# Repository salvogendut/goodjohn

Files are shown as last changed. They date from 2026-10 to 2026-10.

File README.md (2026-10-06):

# Goodjohn

Goodjohn is a Raspberry Pi Pico interface for using an Amstrad CPC keyboard as
a USB keyboard on a PC. This repository holds the firmware, wiring guides and
a prototype Pico carrier PCB.

> [!WARNING]
> **USB keyboard use only.** Physically disconnect the keyboard from the CPC
> motherboard before connecting it to the Pico, even if the CPC is powered off.
> **The keyboard cannot operate the CPC and the PC at the same time.** This
> interface does not provide simultaneous use or a pass-through connection to
> the CPC. Switching the CPC off is not a substitute for disconnecting it.

The first prototype uses an **original RP2040 Pico**, an **English CPC/QWERTY
keyboard**, and **exclusive control of a keyboard disconnected from the CPC
motherboard**. These are the agreed initial requirements. The passive keyboard
connects to Pico GPIO; the Pico's USB connector connects to the PC.

Minimal wiring from a Raspberry Pi Pico to a 19-pin CPC keyboard connector

The drawing's **J1 adapter connector** uses the contact numbering of Bread80's
CPC464 **J3 keyboard connector**. Its square contact 1 is shown at the bottom;
labels give **GPIO / physical Pico pin**. See the [pinout sheet](docs/pinout.pdf)
for connector checks and assembly details.

**Original CPC464 PCB-style keyboard:** use the inline wiring above. Its
19-signal connector pinout is shared by rgbwalker's keyboard and Bread80's
CPC464 SMT **J3** connector. Some versions use a 20-position footprint with one
unused contact. Later CPC464 membrane keyboards use the two-ribbon connection
described below; connector orientation must still be checked on the actual board.

## Current state

There is a buildable C firmware foundation using the Raspberry Pi Pico SDK and
TinyUSB, plus native tests. It scans the physical 10-by-9 CPC464 wiring, debounces
each contact for 5 ms, and sends standard USB HID boot-keyboard reports. The
default scan period is 1 ms. Reports support six regular keys plus modifiers;
more regular keys produce HID ErrorRollOver until the count falls back to six.

Boards without diodes use conservative ghost suppression: new presses in an
ambiguous rectangle are blocked, while already accepted keys and unrelated keys
continue to work. This cannot recover arbitrary chords or detect a release that
is electrically hidden by other held keys. Fully diode-isolated boards can turn
the filter off at build time.

**Status: host tests pass; basic typing works on rgbwalker V1.2.** On 2026-10-06,
the user confirmed the complete number row (`1234567890`), all three letter rows,
Esc and main Enter with the completed 19-wire direct harness. Replacing the
earlier ribbon/jumper path resolved the incorrect characters using the existing
firmware and pin map. The exact fault in that earlier assembly is still unknown.
See the [staged wiring checks and test record](docs/wiring.md#staged-bring-up-for-rgbwalker-v12).

The remaining individual keys, modifiers, chords, cable timing, and USB
suspend/resume and current still need recorded bench tests. The carrier PCB
below is designed and checked, but has not been manufactured or bench-tested.

## Pico carrier PCB prototype

The [v1 carrier](hardware/pico-carrier-v1/README.md) is an **80 × 66 mm, two-layer
board** with a socketed RP2040 Pico, the inline 19-pin connector and separate
10-pin ribbon A/B headers. Use one keyboard through **J1 OR J2 + J3**. It keeps
the tested firmware pin map and powers the Pico through its existing USB port.

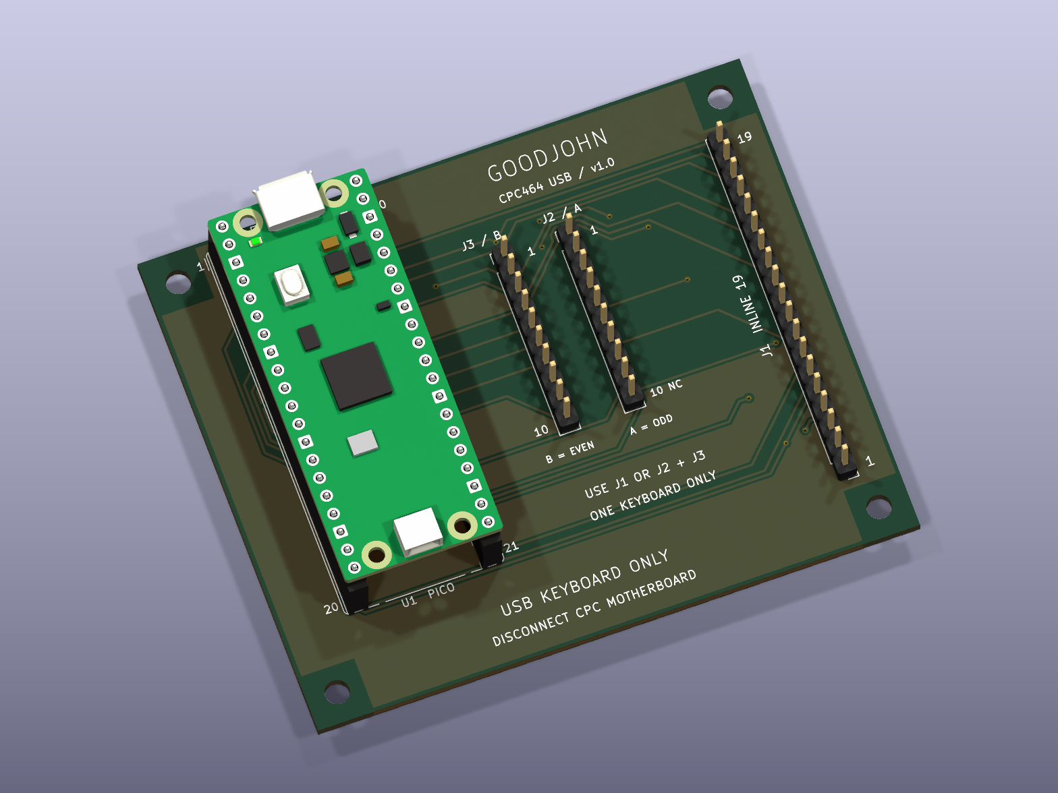
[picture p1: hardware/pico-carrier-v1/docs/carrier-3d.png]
KiCad render of the Goodjohn Pico carrier prototype


The [KiCad project](hardware/pico-carrier-v1/goodjohn-carrier.kicad_pro),
[schematic PDF](hardware/pico-carrier-v1/docs/schematic.pdf),
[assembly guide](hardware/pico-carrier-v1/docs/assembly.pdf),
[BOM](hardware/pico-carrier-v1/bom.csv) and
[Gerber/drill ZIP](hardware/pico-carrier-v1/fabrication/goodjohn-carrier-v1-gerbers.zip)
are included. ERC, DRC and schematic/PCB parity checks pass; an independent
pin-map check matches all 19 signals to the firmware and existing wiring SVGs.
**This is an unbuilt prototype, and the CPC motherboard must remain physically
disconnected.** The carrier headers accept 2.54 mm mating harnesses; bare
membrane tails need an appropriate connector adapter.

## Keyboard projects

| Project | Initial integration |
| --- | --- |
| [rgbwalker's CPC464 Cherry keyboard](https://github.com/rgbwalker/Amstrad_CPC_464_new_Cherry_Keyboard) | V1.2: digits, all letter rows, Esc and main Enter confirmed with a direct 19-wire harness. Further key/chord tests pending; retain ghost suppression. |
| [Bread80 CPC464 SMT mechanical keyboard](https://github.com/Bread80/CPC_Keyboards/tree/main/Keyswitch_CPC464_SMT) | J3 inline and J1 two-ribbon schemes traced from the KiCad PCB. J1 uses CPC464 link settings; hardware validation pending. Verified per-key diodes allow disabling ghost suppression. |
| [Bread80 tactile keyboard](https://github.com/Bread80/CPC_Keyboards/tree/main/Tactile) | Same CPC key arrangement, no diodes; connector adapter still needs checking. |
| [Bread80 CPC6128 SMT keyboard](https://github.com/Bread80/CPC_Keyboards/tree/main/Keyswitch_CPC6128_SMT) | Upstream describes this as a design-stage board; not a validated adapter target. |

Start with [the wiring notes](docs/wiring.md). Connector families are not
interchangeable just because the logical CPC matrix is the same.

For the workbench, use the [ASCII pinout sheet](docs/pinout.txt) or the
[four-page printable PDF](docs/pinout.pdf). These include the Bread80 J3 wire
list, a full Pico header diagram, assembly steps and continuity checks, plus
V1.2 connector orientation and a direct two-wire test for rgbwalker. Regenerate
both with `python3 scripts/generate_pinout.py` after installing
`scripts/requirements-docs.txt` in a Python virtual environment.
Regenerate the README's [SVG wiring diagram](docs/wiring.svg) with
`python3 scripts/generate_wiring_svg.py` in the same environment. It reuses the
Pico artwork from the supplied [pico-pinout.svg](pico-pinout.svg) and the same
firmware-derived wiring data as the sheets.

### Alternate connection: two 10-pin ribbons

Bread80's **CPC464 SMT keyboard J1**, configured for CPC464, can use two 10-way
ribbons with the existing Pico GPIO assignments. Bridge **LK1 pads 1-2** and
**LK2 pads 1-2**; leave **LK3 and the bonus links open**. This alternate harness
is source-checked and has not yet been bench-tested.

Bread80 J1 two-ribbon wiring to Raspberry Pi Pico

The diagram distinguishes ribbon positions from J1 PCB pad numbers. **J1 pad 19
is unused; pad 20 is connected.** Here J1 refers to Bread80's keyboard connector.
Use the [complete wiring scheme and orientation guide](docs/wiring-dual-ribbon.md),
[ASCII pinout](docs/pinout-dual-ribbon.txt), or [two-page PDF](docs/pinout-dual-ribbon.pdf).
This mapping is specific to the CPC464 setting; CPC6128 and Tactile connectors
need separate mappings. Regenerate these files with
`python3 scripts/generate_dual_ribbon.py` in the same documentation environment.

### Original CPC464 keyboard PCB

The original CPC464 keyboard PCB with the inline 19-wire connection is also
expected to work: its passive switch matrix matches the arrangement targeted
by this firmware, as shown in the
[Amstrad service manual](https://retronik.silicium.org/DOCUMENTS/Info/Amstrad_CPC/Amstrad%20CPC464%20CTM640%20GT64%20Service%20Manual.pdf).
The existing keymap should apply to the English/QWERTY version.

Disconnect the keyboard from the CPC motherboard, even when the CPC is powered
off; the Pico takes over keyboard scanning. Verify your connector's numbering,
orientation and switch continuity against the wiring notes before connecting it.
Keep `GOODJOHN_MATRIX_HAS_DIODES=OFF` (the default), since the original matrix
lacks per-key diodes and needs ghost suppression. Compatibility is expected but
has not yet been tested on original hardware; other connector revisions may
require a different harness.

## Build

Prerequisites: CMake, Make or Ninja, Python 3, an Arm bare-metal GCC toolchain
(`arm-none-eabi-gcc` and `arm-none-eabi-g++`), and the Pico SDK. A native C++
compiler is also needed if the SDK builds picotool instead of using an installed
copy. The development build was checked with SDK **2.2.0**, its pinned TinyUSB
submodule, Arm GNU **14.2.Rel1**, and picotool **2.3.1**.

For an SDK checkout outside this repository:

```sh
git clone --branch 2.2.0 --depth 1 https://github.com/raspberrypi/pico-sdk.git ../pico-sdk
git -C ../pico-sdk submodule update --init --depth 1 lib/tinyusb
cmake -S . -B build -DPICO_SDK_PATH="$(pwd)/../pico-sdk" -DPICO_BOARD=pico -DCMAKE_BUILD_TYPE=Release
cmake --build build --parallel
```

Put the compiler's `bin` directory on `PATH`, or set
`-DPICO_TOOLCHAIN_PATH=/path/to/arm-toolchain`. CMake uses an installed picotool
when available (`-Dpicotool_DIR=/path/to/picotool/cmake-directory`); otherwise the
SDK downloads and builds it, which needs network access.

The output is `build/goodjohn.uf2`. Hold BOOTSEL while connecting the Pico over
USB, then copy the UF2 to its `RPI-RP2` volume. This replaces the existing Pico
application. No hardware has been flashed as part of the initial setup.

For a board with verified diodes on every connected switch:

```sh
cmake -S . -B build -DGOODJOHN_MATRIX_HAS_DIODES=ON
cmake --build build --parallel
```

Leave this option OFF for original membranes, the rgbwalker Cherry board, and
the Bread80 tactile board. Edit `src/board_config.h` to change the GPIO wiring.

The default USB VID/PID (`CAFE:4011`) are development placeholders, not an
assignment to this project. A distributed product needs an authorized pair,
set using `GOODJOHN_USB_VID` and `GOODJOHN_USB_PID` CMake variables.

## Initial key behavior

The keymap sends PC key usages, not CPC character codes. Select the desired PC
keyboard layout in the host OS. Letters and digits follow English QWERTY, but
shifted symbols are not guaranteed to match the CPC legends.

| CPC key | PC behavior |
| --- | --- |
| DEL / CLR | Backspace / forward Delete |
| Main Enter / keypad Enter | Enter / keypad Enter |
| COPY | Left Alt |
| Either Shift | Left Shift (both switches share one matrix contact) |
| CTRL / CAPS LOCK | Left Control / Caps Lock |
| Numeric keypad | PC keypad usages; Num Lock state is controlled by the host |
| `^ £` / `- =` / `@ \|` | PC Equal / Minus / Grave key positions |
| `; +` / `: *` | PC Semicolon / Apostrophe key positions |
| Bread80 bonus switches | Unmapped initially |

There is no Fn layer yet, so F1–F12, GUI and Num Lock have no default bindings.
For early testing, set Num Lock using the PC's existing or on-screen keyboard.
The map lives in `src/keymap.c`; exact CPC symbol translation and additional
layouts are separate follow-up work. Host lock LED reports are accepted, but no
physical lock LEDs or USB remote wakeup are implemented.

## Test without a Pico SDK

```sh
cmake -S . -B build-host -DGOODJOHN_HOST_TESTS=ON
cmake --build build-host
ctest --test-dir build-host --output-on-failure
```

These tests cover contact bounce, independent debounce clocks, timer wrap,
ambiguous chords and recovery, the separate DEL column, modifier reports,
keypad Enter, and six-key overflow/recovery. They do not simulate USB hardware.

## Next hardware milestone

1. Pick the exact keyboard PCB revision and verify the connector with a meter.
2. Wire a Pico prototype and check single keys, modifiers, DEL, both Enter keys,
   press/release bounce and multi-key chords on a PC.
3. Measure scan settling with the intended cable, check suspend/resume and
   reconnect behavior, and settle the missing PC-key bindings.
4. Capture the proven wiring in an interface schematic and PCB with appropriate
   connector orientation, protection and optional lock LEDs.

## References

The adjacent keyboard projects are reference inputs and retain their respective
licenses; no upstream PCB or image assets are copied into this repository.
Exact local revisions and electrical findings are recorded in
[the wiring notes](docs/wiring.md).

Firmware references: [Pico SDK 2.2.0](https://github.com/raspberrypi/pico-sdk/tree/2.2.0),
[Raspberry Pi's USB HID example](https://github.com/raspberrypi/pico-examples/tree/master/usb/device/dev_hid_composite),
[TinyUSB](https://docs.tinyusb.org/), and
[Pico board documentation](https://www.raspberrypi.com/documentation/microcontrollers/pico-series.html).

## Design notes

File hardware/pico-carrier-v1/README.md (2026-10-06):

# Goodjohn Pico carrier v1

An **80 × 66 mm, two-layer, hand-solderable carrier** for an original RP2040
Raspberry Pi Pico / Pico H. It replaces the tested direct jumper wiring with
PCB tracks and offers both CPC464 connector arrangements. The existing firmware
and GPIO assignments apply without changes.

**Status: unbuilt prototype.** KiCad 10.0.6 ERC and DRC pass with zero violations,
zero unconnected items and zero schematic parity issues. The actual schematic
and PCB nets also match the firmware and both existing wiring diagrams. This
PCB has not been manufactured or bench-tested; the earlier successful typing
test used a direct harness with rgbwalker V1.2.

> [!WARNING]
> **USB keyboard only. Physically disconnect the keyboard from the CPC
> motherboard, even when the CPC is powered off.** The keyboard cannot operate
> the CPC and PC simultaneously. This carrier has no switching, isolation or
> CPC pass-through circuitry. Connect one keyboard using **J1 OR J2 + J3**.

KiCad 3D render of the Pico carrier prototype

The image is a KiCad render, not a photograph of manufactured hardware.

## Files to use

- Open [goodjohn-carrier.kicad_pro](goodjohn-carrier.kicad_pro) in **KiCad 10**.
  The [schematic](goodjohn-carrier.kicad_sch), [routed PCB](goodjohn-carrier.kicad_pcb),
  project-local symbol/footprint libraries and library tables are included.
- Read the [schematic PDF](docs/schematic.pdf), [assembly PDF](docs/assembly.pdf),
  [component-side SVG](docs/assembly-top.svg) and [complete connector CSV](docs/connections.csv).
- Prototype manufacturing package:
  [Gerber + drill ZIP](fabrication/goodjohn-carrier-v1-gerbers.zip),
  [individual files](fabrication/gerbers), [fabrication notes](fabrication/README.md).
- [BOM](bom.csv), [pin-map verification](checks/pinmap.json),
  [ERC report](checks/erc.json), [DRC report](checks/drc.json).

## Connections and orientation

All three keyboard headers are ordinary **2.54 mm single-row male headers**.
Use a continuity-checked mating cable or adapter. They are not native FFC/FPC
sockets for inserting a bare original membrane tail.

With the carrier component side facing you and the Pico USB socket at the top:

| Carrier connector | Placement and pin 1 | Keyboard connection |
| --- | --- | --- |
| **U1** | Pico at left; physical pin 1 upper left, pin 40 upper right | Two 1×20 female sockets, rows 17.78 mm apart; USB faces the upper board edge |
| **J1** | 1×19 at right; **pin 1 is at the bottom**, pin 19 at the top | Inline 19-signal pinout: rgbwalker V1.2, Bread80 CPC464 SMT **J3**, original CPC464 PCB-style keyboard |
| **J2 / A** | Right-hand 1×10 ribbon header; **pin 1 at top** | Ribbon A, Bread80 keyboard **J1 odd pads** 1, 3, …, 19 |
| **J3 / B** | Left-hand 1×10 ribbon header; **pin 1 at top** | Ribbon B, Bread80 keyboard **J1 even pads** 2, 4, …, 20 |

Carrier reference names differ from keyboard reference names. **Follow contact
numbers, not apparent left-to-right order, ribbon colors or connector names.**
Match square pad 1 at both ends. The inline carrier header is intentionally
opposite in vertical numbering to the keyboard's Esc-end pin 1; a cable must
still connect contact 1 to contact 1, 2 to 2, and so on.

For Bread80's **two-ribbon J1 connection in CPC464 mode**, bridge keyboard
**LK1 pads 1–2** and **LK2 pads 1–2**; leave **LK3 and bonus links open**.
Carrier **J2.10 / A10 / keyboard J1.19 is unused**.
Carrier **J3.10 / B10 / keyboard J1.20 is required** and carries Y1.
These link settings belong to the keyboard PCB; there are no links to set on
the carrier. For the inline Bread80 J3 connection, retain the original
[inline wiring instructions](../../docs/wiring.md).

On rgbwalker V1.2 the optional twentieth contact is unused. Do not confuse that
contact with Bread80 two-ribbon J1 pad 20. Original keyboard compatibility is
expected from the pinout but has not been bench-tested. CPC6128 and Bread80
Tactile connectors are not validated targets for this carrier.

The 19 contacts carry matrix signals only. No keyboard contact connects to
ground, 3.3 V or 5 V. Ground planes join only the Pico's GND header pins.
Unused Pico GPIO, AGND, VBUS, VSYS, 3V3 and control pins have isolated pads.
The Pico receives power and exchanges data over **one USB data cable to the PC**;
no second USB port or hub is required. This simple carrier adds no input
protection or motherboard isolation; attach the harness with USB unplugged.

## Parts and assembly

The [BOM CSV](bom.csv) specifies generic mechanical requirements rather than
unverified supplier part numbers. Before buying, compare actual connector
drawings and socket height with the supplied footprints and assembly drawing.

| Item | Quantity | Specification |
| --- | ---: | --- |
| Carrier PCB | 1 | Two layers, 1.6 mm FR4, 35 µm / 1 oz copper |
| U1 module | 1 | Original RP2040 Pico with downward male headers, or Pico H; not a bare RP2040 chip |
| U1 sockets | 2 | 1×20 female, vertical, 2.54 mm pitch; 17.78 mm row spacing; nominal 8.5 mm body height |
| J1 | 1 | 1×19 male, vertical, 2.54 mm pitch, 0.64 mm square posts |
| J2, J3 | 2 | 1×10 male, vertical, 2.54 mm pitch, 0.64 mm square posts |
| Mounting hardware | Optional 4 sets | M3 standoffs/screws; 3.2 mm unplated holes; washer/head envelope ≤7 mm |
| Cables | As needed | USB data cable plus one of the two checked keyboard harnesses |

You may leave the unused keyboard connector option unpopulated. Both options
may be soldered, but only one keyboard/harness option should be plugged in.

1. Leave the Pico, keyboard and USB disconnected. Inspect the bare PCB and
   solder U1's two female sockets, keeping them parallel and flush. Fit the
   chosen keyboard headers. Pin 1 is the square pad.
2. With **U1 still removed**, check every cable end to the corresponding Pico
   socket contact using [connections.csv](docs/connections.csv). All 19 paths
   should have continuity. Different matrix nets, matrix-to-GND and
   matrix-to-power pads must remain isolated. A10 must remain isolated too.
3. Check U1 ground contacts 3, 8, 13, 18, 23, 28 and 38 have continuity with
   one another. Confirm there are no shorts between the unused supply pads.
4. Connect the detached keyboard using just one connector option. With USB
   unplugged and the Pico still removed, verify key-operated continuity using
   the table below: it appears only while the indicated key is held. Check
   the complete cable path, not only the keyboard connector.
5. Insert the Pico with its USB socket facing the board's top edge. Flash the
   existing Goodjohn UF2 via BOOTSEL if needed, then use a PC USB data cable.
   Keep ghost suppression enabled (`GOODJOHN_MATRIX_HAS_DIODES=OFF`) unless
   the attached keyboard's diode arrangement has been verified.
6. Record Esc, digits, letters, Enter, Space, DEL, modifiers and chords in a
   text editor. The two-ribbon board and original keyboard still need actual
   hardware validation; record the board version and harness used.

| Key | Inline carrier contacts | Two-ribbon carrier contacts | Pico physical contacts |
| --- | --- | --- | --- |
| Top-row 1 | J1.3 + J1.11 | J2.2 + J3.2 | 16 + 14 |
| Top-row 2 | J1.4 + J1.11 | J2.3 + J3.2 | 17 + 14 |
| Esc | J1.5 + J1.11 | J2.4 + J3.2 | 19 + 14 |
| Main Enter | J1.5 + J1.17 | J2.4 + J3.8 | 19 + 6 |
| Space | J1.10 + J1.14 | J3.1 + J3.5 | 25 + 10 |
| DEL / USB Backspace | J1.1 + J1.2 | J2.9 + J2.1 | 26 + 15 |

Diode-equipped keyboards may require the meter's diode-test mode and correct
probe polarity instead of a continuity beep.

## Mechanical details

Board outline: **80 × 66 mm**, four straight edges, no panelization. Hole
centres measured from the upper-left board corner are **(4,4), (76,4),
(4,62), (76,62) mm**. All four holes are 3.2 mm NPTH; 7 × 7 mm areas around
them exclude tracks, vias and copper pours. This layout has no CPC case fit
claim. Insulate the underside from metalwork and support the board on standoffs.

Pico socket pin 1 is at (10.16, 3.048) mm from that corner; the second socket
row is 17.78 mm to the right. The Pico USB connector faces outwards near the
top edge. Verify the chosen cable plug and socket stack height during the
first physical assembly; the 3D library model is illustrative.

## Editing and rebuilding outputs

The committed `.kicad_sch` and `.kicad_pcb` are the editable design authority.
Use KiCad's normal editors and Update PCB from Schematic for further changes.
Local symbol and footprint libraries make the design independent of sibling
repositories. Standard KiCad 10 3D libraries are needed only for 3D viewing.

See [the hardware tooling instructions](../tools/README.md) for validation,
export and regeneration. Placement was generated with KiCad's Python API and
routed locally with Freerouting **2.5.0**; the final board includes a ground
stitching via at board coordinates (119,120) mm to join a copper strip.
There are 13 vias, all 0.8 / 0.4 mm, and 0.30 mm signal tracks. Minimum design
clearance is 0.25 mm; the router used 0.30 mm. Neither ERC nor DRC suppresses
violations with exclusions.

Pinout provenance and previous bench evidence remain in the repository's
[inline](../../docs/wiring.md) and [two-ribbon](../../docs/wiring-dual-ribbon.md)
notes. Module mechanics come from the
[Raspberry Pi Pico datasheet](https://datasheets.raspberrypi.com/pico/pico-datasheet.pdf)
and the KiCad footprint; [library attribution and changes](libraries/README.md)
are recorded separately. See the [validation record](checks/README.md) for the
checks completed and the remaining physical prototype work.

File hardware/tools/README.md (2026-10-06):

# Hardware tooling

The saved KiCad files are the design authority. Normal edits do not require
regenerating the schematic or placement. Run these commands from the repository
root; keep the same KiCad major version (10) for reproducible validation.

## Refresh checked outputs

Install `scripts/requirements-docs.txt` into a Python virtual environment, then:

```sh
python hardware/tools/export.py --flatpak
```

Omit `--flatpak` for native `kicad-cli`. This performs ERC, netlist export,
DRC with schematic parity and zone refill, independent pin-map validation,
schematic PDF, assembly SVG, 3D render, Gerber/drill export, BOM/connector CSV,
assembly PDF and a checksummed manufacturing ZIP. It stops on a failing check.
Standard KiCad 3D libraries must be installed for the render.
The package step independently compares all Excellon drill coordinates and
diameters to the PCB and checks the exported outline corners and stack metadata.

`verify.py` compares the actual schematic netlist and PCB pad nets against
`src/board_config.h` and both pre-existing wiring SVGs. It also checks isolated
pins, ground, trace/via dimensions, the project's manufacturing minimums and
the ERC/DRC reports. It needs only Python's standard library. It does not claim
to simulate the keyboard or prove physical cable orientation.

## Recreate the initial design or reroute

These commands **replace schematic/placement/routing** and are intended for
reviewed regeneration, not routine editing of the finished board.

```sh
python hardware/tools/design.py --schematic
flatpak run --command=kicad-cli org.kicad.kicad sch export netlist \
  hardware/pico-carrier-v1/goodjohn-carrier.kicad_sch --format kicadxml \
  --output hardware/pico-carrier-v1/checks/netlist.xml
flatpak run --command=python3 org.kicad.kicad hardware/tools/design.py --pcb
flatpak run --command=python3 org.kicad.kicad hardware/tools/route.py \
  --export hardware/pico-carrier-v1/checks/carrier.dsn
```

The verified router was the official **Freerouting 2.5.0** JAR, running locally
under OpenJDK 25. It is not bundled. With its path substituted below:

```sh
java -Djava.awt.headless=true -jar /path/to/freerouting-2.5.0.jar \
  --gui.enabled=false --api_server.enabled=false -da \
  -de hardware/pico-carrier-v1/checks/carrier.dsn \
  -do hardware/pico-carrier-v1/checks/carrier.ses -mp 20 -mt 2
flatpak run --command=python3 org.kicad.kicad hardware/tools/route.py \
  --import-session hardware/pico-carrier-v1/checks/carrier.ses
python hardware/tools/export.py --flatpak
```

The committed DSN and SES record the routing input/result. The import helper
restores all tracks to 0.30 mm (the router can narrow short pad exits) and adds
the v1 ground stitch at (119,120) mm. If routing or placement changes, recheck
that stitch and every design rule; a new run may need different local fixes.
Export strips ordinary pours from the temporary routing copy so all ground
pins get explicit tracks; mounting rule areas remain. Pours stay in the saved
board and are filled by KiCad. `routing-input.kicad_pcb` is disposable/ignored.

KiCad's Python `LoadBoard` can use default net-class settings rather than the
adjacent project. The exchange script explicitly supplies 0.30 mm track/clearance
and 0.80/0.40 mm vias. It preserves the project file across API saves, which can
otherwise reset design constraints in this environment. Check the DSN rules,
the actual imported dimensions and the `.kicad_pro` minimums, not only a successful
tool exit. Final manufacturing minimums are 0.25 mm width/clearance.

For refreshing vendored libraries, use `design.py --libraries PATH`, where PATH
contains KiCad's `symbols/` and `footprints/` directories. Review all library
changes and preserve [the license/provenance](../pico-carrier-v1/libraries/README.md).
That command is not needed to open, edit, validate or export the delivered design.

Official references:
[KiCad CLI](https://docs.kicad.org/10.0/en/cli/cli.html),
[Freerouting CLI](https://github.com/freerouting/freerouting/blob/v2.5.0/docs/command_line_arguments.md).

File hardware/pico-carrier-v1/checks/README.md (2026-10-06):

# Validation record

Checked on 2026-10-06 with KiCad 10.0.6. The carrier is an **unbuilt prototype**;
these are design/file checks, not recorded physical measurements.

| Check | Result |
| --- | --- |
| [Schematic ERC](erc.json) | 0 violations at enabled error/warning severities |
| [PCB DRC](drc.json) | 0 violations, 0 unconnected items, 0 schematic parity issues |
| [Independent pin-map check](pinmap.json) | 19 matrix nets / 57 signal pads match firmware and both wiring SVGs; seven GND pads and all isolated pins checked |
| [Fabrication check](fabrication.json) | 92 PTH + 4 NPTH drill positions/diameters match final PCB; outline 80 × 66 mm; 2 layers / 1.6 mm |
| Visual review | Schematic PDF, both assembly PDF pages, component-side SVG and complete 3D preview inspected |
| Regeneration | Separate ignored build directory: regenerated schematic/placement, imported saved SES, applied v1 routing adjustments, reran ERC/DRC/parity/pin-map checks; all passed |

Final board rules enforce 0.25 mm minimum trace width and copper clearance,
0.80 mm minimum via diameter, 0.20 mm minimum via annulus, 0.50 mm copper-to-edge
clearance and 0.15 mm silkscreen clearance. Actual tracks are 0.30 mm; vias are
0.80 / 0.40 mm. No DRC exclusions are recorded. Normal KiCad default ignored
ERC categories are listed in its report.

`carrier.dsn` and `carrier.ses` preserve the local Freerouting input/result.
The final PCB also contains the uniform-width and ground-stitch adjustments
performed by `hardware/tools/route.py`; the SES alone is not the final PCB.
See [the tooling guide](../../tools/README.md) before regenerating anything.

Manufacturing artifacts and design files are covered by the
[SHA256 manifest](../fabrication/SHA256SUMS.txt). Revalidate and regenerate
exports after changing the schematic, PCB or manufacturing rules.

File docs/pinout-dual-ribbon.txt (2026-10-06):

GOODJOHN - BREAD80 CPC464 SMT J1 / TWO 10-PIN RIBBONS
Revision 2 / 2026-10-06
SOURCE-CHECKED; NOT BENCH-TESTED. CPC464 CONFIGURATION ONLY.

WARNING: USB KEYBOARD USE ONLY. No simultaneous CPC/PC keyboard operation.
Physically disconnect keyboard from CPC motherboard, even when powered off.
There is no pass-through mode. Switching the CPC off is not enough.
Unplug USB before wiring or meter checks.
LK1: bridge 1-2 only. LK2: bridge 1-2. LK3 and LK4-LK6: OPEN.
19 signal wires; no keyboard power or ground wire. Pico USB goes to PC.

       KEYBOARD COMPONENT SIDE / KEYS FACING YOU
                    Rear / Esc end

           Ribbon B             Ribbon A
              B1 ( 2)          [ 1] A1  square pad
              B2 ( 4)          ( 3) A2
              B3 ( 6)          ( 5) A3
              B4 ( 8)          ( 7) A4
              B5 (10)          ( 9) A5
              B6 (12)          (11) A6
              B7 (14)          (13) A7
              B8 (16)          (15) A8
              B9 (18)          (17) A9
             B10 (20)          (19) A10 -- no connection

                    Space-bar end
       Parenthesized numbers are Bread80 J1 PCB pad numbers.

A/B are guide labels. A = odd J1 pads; B = even J1 pads.
J1 pad 19 (A10) is unused. J1 pad 20 (B10) MUST be wired.

Ribbon   J1 pad   Net    Pico GPIO   Pico PHYSICAL pin
------------------------------------------------------------------------
A1       1        Y10    GP11        15
A2       3        X1     GP12        16
A3       5        X2     GP13        17
A4       7        X3     GP14        19
A5       9        X4     GP15        20
A6       11       X5     GP16        21
A7       13       X6     GP17        22
A8       15       X7     GP18        24
A9       17       X9     GP20        26
A10      19       NC     --          Leave disconnected
B1       2        X8     GP19        25
B2       4        Y9     GP10        14
B3       6        Y8     GP9         12
B4       8        Y7     GP8         11
B5       10       Y6     GP7         10
B6       12       Y5     GP6         9
B7       14       Y4     GP5         7
B8       16       Y3     GP4         6
B9       18       Y2     GP3         5
B10      20       Y1     GP2         4

Link checks, no keys held: J1.1 -> J3.2 (Y10); J1.2 -> J3.10 (X8).
Both must conduct. LK3 must not short J3.10 (X8) to J3.1 (X9).

Start with A2/J1.3 -> Pico16 and B2/J1.4 -> Pico14; top-row 1 types 1.
Unplug USB between changes. Add A3/J1.5 -> Pico17 for 2;
A4/J1.7 -> Pico19 for Esc; then complete the harness above.
Existing firmware GPIO/keymap applies. Diode option ON only after
all switch diodes and their orientation have been verified.

SWITCH CHECKS: detach keyboard from Pico; red on X, black on Y.
Use diode mode on the SMT board. Pressed: conducts; released: open.
Key                Ribbon X/Y   J1 pads X/Y   Pico physical X/Y
Top-row 1          A2 / B2      3 / 4         16 / 14
Top-row 2          A3 / B2      5 / 4         17 / 14
Esc                A4 / B2      7 / 4         19 / 14
Space              B1 / B5      2 / 10        25 / 10
Either Shift       A7 / B8      13 / 16       22 / 6
DEL (Backspace)    A9 / A1      17 / 1        26 / 15
Main Enter         A4 / B8      7 / 16        19 / 6
Cursor Up          A2 / B10     3 / 20        16 / 4

Do not apply to CPC6128 settings, J2 modular, Tactile J2/J3, or an
unverified original membrane tail. The original 19-pin SVG's adapter
J1 and this KEYBOARD J1 are different connector references.

PCB source:
https://github.com/Bread80/CPC_Keyboards/blob/bf4a6052888fef27ca01a6b0983791d7cb4e8af1/Keyswitch_CPC464_SMT/Keyboard.kicad_pcb
Schematic:
https://github.com/Bread80/CPC_Keyboards/blob/bf4a6052888fef27ca01a6b0983791d7cb4e8af1/Keyswitch_CPC464_SMT/Keyboard.kicad_sch
Full notes: docs/wiring-dual-ribbon.md
Regenerate: python3 scripts/generate_dual_ribbon.py

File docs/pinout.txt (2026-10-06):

GOODJOHN - CPC KEYBOARD TO RASPBERRY PI PICO
Revision 5 / 2026-10-06
============================================================================
TARGET: Bread80 Keyswitch_CPC464_SMT, connector J3 (19 pins).
PICO: original non-wireless RP2040 Pico / Pico H; component side up.
STATUS: source-checked; rgbwalker V1.2 basic typing passed (section 6).
Further individual key, chord and USB hardware tests remain pending.
Firmware GPIO assignments: src/board_config.h.

WARNING: USB KEYBOARD USE ONLY. No simultaneous CPC/PC keyboard operation.
DISCONNECT the keyboard from the CPC motherboard, even with CPC power off.
There is no pass-through mode. Switching the CPC off is not enough.
Use 19 signal wires. No keyboard VCC or GND wire is required for this matrix.
Do not wire a matrix contact to 5 V, VBUS, VSYS, 3V3 or GND.
Power the Pico from the PC using a USB data cable.

  Passive keyboard          Raspberry Pi Pico                 PC
  [J3: 19 contacts] -------> [GP2..GP20, as below] --- USB ---> [USB port]
  No CPC motherboard connection.

1. WIRE LIST - J3 PAD ORDER
----------------------------------------------------------------------------
J3 pad   Matrix net   Pico GPIO   Pico PHYSICAL pin   Function
  01       X9            GP20             26           Sense input
  02       Y10           GP11             15           Scan output
  03       X1            GP12             16           Sense input
  04       X2            GP13             17           Sense input
  05       X3            GP14             19           Sense input
  06       X4            GP15             20           Sense input
  07       X5            GP16             21           Sense input
  08       X6            GP17             22           Sense input
  09       X7            GP18             24           Sense input
  10       X8            GP19             25           Sense input
  11       Y9            GP10             14           Scan output
  12       Y8            GP9              12           Scan output
  13       Y7            GP8              11           Scan output
  14       Y6            GP7              10           Scan output
  15       Y5            GP6              09           Scan output
  16       Y4            GP5              07           Scan output
  17       Y3            GP4              06           Scan output
  18       Y2            GP3              05           Scan output
  19       Y1            GP2              04           Scan output

GPIO numbers and physical header pin numbers are different.
Example: J3 pad 1 -> GP20 -> physical Pico pin 26 (NOT pin 20).

J3 orientation: with keyboard keys facing you, cursor keys at upper
right, J3 is the single vertical row at the far left. On the inspected
PCB, pad 1 is square and at the Esc end; pad 19 is at the Caps end.
Locate the square copper pad before fitting a cable. The solder side
is mirrored; follow pad numbers, never an assumed cable color order.

       Esc/rear end
         [01]  square pad
         (02)
         (03)
          ...
         (19)
       Caps/front end

Leave LK1, LK2, LK3 and bonus-switch links LK4, LK5, LK6 OPEN.
LK3 would join X8 and X9. J1/J2 use different pin orders.

2. PICO TOP VIEW - USB AT TOP, COMPONENTS FACING YOU
----------------------------------------------------------------------------
                              USB to PC
                           +----USB----+
            GPIO/net/J3    |           |   GPIO/net/J3
        GP0      unused 01 |           | 40 VBUS     unused
        GP1      unused 02 |           | 39 VSYS     unused
        GND      unused 03 |           | 38 GND      unused
         GP2  Y1  J3.19 04 |           | 37 3V3_EN   unused
         GP3  Y2  J3.18 05 |           | 36 3V3(OUT) unused
         GP4  Y3  J3.17 06 |           | 35 ADC_VREF unused
         GP5  Y4  J3.16 07 |           | 34 GP28     unused
        GND      unused 08 |           | 33 AGND     unused
         GP6  Y5  J3.15 09 |           | 32 GP27     unused
         GP7  Y6  J3.14 10 |           | 31 GP26     unused
         GP8  Y7  J3.13 11 |           | 30 RUN      unused
         GP9  Y8  J3.12 12 |           | 29 GP22     unused
        GND      unused 13 |           | 28 GND      unused
         GP10 Y9  J3.11 14 |           | 27 GP21     unused
         GP11 Y10 J3.02 15 |           | 26 GP20 X9  J3.01
         GP12 X1  J3.03 16 |           | 25 GP19 X8  J3.10
         GP13 X2  J3.04 17 |           | 24 GP18 X7  J3.09
        GND      unused 18 |           | 23 GND      unused
         GP14 X3  J3.05 19 |           | 22 GP17 X6  J3.08
         GP15 X4  J3.06 20 |           | 21 GP16 X5  J3.07
                           +-----------+
                    SWD pads are not used.
'unused' = leave unconnected for this keyboard harness.
All numbers next to the board outline are PHYSICAL header pin numbers.

3. BUILD AND ASSEMBLE
----------------------------------------------------------------------------
1) Disconnect all power. Identify the board revision and J3 pad 1.
2) Open the links listed above. Fit Pico headers if needed.
3) Run 19 insulated wires using the wire list. Label both cable ends.
   Keep the prototype cable short; verify every connection with a meter.
4) Check the switch pairs below and check for unintended adjacent shorts.
5) Build/flash build/goodjohn.uf2, then connect Pico USB to the PC.
   For BOOTSEL flashing, hold BOOTSEL while plugging in USB and copy
   the UF2 to RPI-RP2. No existing CPC electronics should be attached.

Bread80 SMT with every diode present and oriented correctly:
  cmake -S . -B build -DGOODJOHN_MATRIX_HAS_DIODES=ON
  cmake --build build --parallel

Original membrane / rgbwalker / Bread80 tactile / uncertain diodes:
  cmake -S . -B build -DGOODJOHN_MATRIX_HAS_DIODES=OFF
  cmake --build build --parallel
These commands reconfigure an existing build; see README.md for SDK setup.

4. UNPOWERED SWITCH TESTS
----------------------------------------------------------------------------
Disconnect the keyboard from both Pico and CPC for these switch tests.
Key             Matrix pair        J3 pad pair     Pico physical pair
Cursor Up       Y1/X1              19/3            4/16
A               Y9/X6              11/8            14/22
Space           Y6/X8              14/10           10/25
Either Shift    Y3/X6              17/8            6/22
DEL             Y10/X9             2/1             15/26
Main Enter      Y3/X3              17/5            6/19
Keypad Enter    Y1/X7              19/9            4/24

For SMT diodes, use diode mode with red probe on X and black on Y.
Press the key: forward conduction. Release it: open. Reverse polarity
should block on a diode board. On a plain switch board, continuity
works in either direction. A continuity beeper alone may miss a diode.

Scan current: 3.3 V pull-up -> X -> closed switch -> diode -> selected Y.
              X ---- switch ---- |>| ---- Y
                                  cathode toward Y
Only the selected Y sinks low; all other Y lines float. X lines are inputs.
The pull-ups are internal to the Pico; no external matrix supply is needed.

5. FIRST USB TEST
----------------------------------------------------------------------------
Check every key and release, both Shift keys, Ctrl, COPY, both Enter keys
and DEL. COPY sends Alt; DEL sends Backspace; CLR sends forward Delete.
Set PC Num Lock for numeric keypad digits. Both Shifts share one contact.
Test chords: diode-less matrices suppress ambiguous new keys, so some
chords will be blocked. Do not disable that filter to cure missing keys.
Above six regular keys, HID reports ErrorRollOver until keys are released.
Exact shifted CPC symbols depend on the PC layout; no Fn layer yet.
V1.2 digits, letters, Esc and main Enter passed; see section 6.
Other keys/chords, USB suspend current and suspend/resume need checks.

6. RGBWALKER V1.2 - CONNECTOR AND DIRECT-WIRE BRING-UP
----------------------------------------------------------------------------
DO NOT treat J3's table as a verified pinout for every 20-pin keyboard.
V1.2 Gerbers: CP002_THT and CP002_SMD contacts 1..19 match each other.
Count square pad as 1 at the Esc end, downward toward Shift.
  contacts 1/2: isolated DEL switch; expected harness GP20/GP11
  contacts 3..10: X1..X8; expected harness GP12..GP19
  contacts 11..19: Y9..Y1; expected harness GP10..GP2
  contact 20: isolated from the matrix in this revision; leave disconnected.
With Pico disconnected, switch pairs are: 1 = 3/11, 2 = 4/11, Esc = 5/11.
The service drawing reverses the two DEL wire names relative to Bread80;
that does not affect the isolated diode-less DEL switch. Keep diodes OFF.

Unplug USB before each wiring change or meter check. Start directly:
  keyboard 3  -> Pico PHYSICAL 16 (GP12)
  keyboard 11 -> Pico PHYSICAL 14 (GP10)
Each pad-to-pad wire path must beep WITHOUT pressing a key. Then power
by USB and press top-row 1. This direct test passed on 2026-10-06.
Bypassing the previous ribbon/jumper assembly restored 1; its exact
fault has not been identified. Firmware and keymap changes were not needed.
Next add keyboard 4 -> Pico 17 (GP13) for 2, then 5 -> Pico 19 (GP14)
for Esc. Check each wire before USB power. Esc prints no character.
Then add contacts 12..16 -> physical pins 12,11,10,9,7 for digits 1..0.
Complete contacts 1..19 using section 1; keep contact 20 disconnected.
USER-CONFIRMED, 2026-10-06: completed 19-wire direct harness passes
1234567890, qwertyuiop, asdfghjkl, zxcvbnm, Esc and main Enter.
Individual remaining keys, modifiers, chords and USB tests are pending.
Before reusing an adapter, map and label every wire with a meter.
For switch-pair identification, disconnect the keyboard from the Pico:
an unpowered Pico can still provide other paths through its circuitry.
Full procedure and test status: docs/wiring.md.

Bread80 J1, CPC464 links: see docs/pinout-dual-ribbon.txt and .pdf.
Bread80 tactile, J2 modular and CPC6128 need their own
connector mapping. An 18-wire harness needs explicit X8/X9 handling.

7. SOURCES AND REGENERATION
----------------------------------------------------------------------------
Bread80 reference: bf4a6052888fef27ca01a6b0983791d7cb4e8af1
https://github.com/Bread80/CPC_Keyboards/blob/bf4a6052888fef27ca01a6b0983791d7cb4e8af1/Keyswitch_CPC464_SMT/Keyboard.kicad_pcb
rgbwalker reference: 588e61006bb606d08cc981467d7990c6e3104c42
https://github.com/rgbwalker/Amstrad_CPC_464_new_Cherry_Keyboard/blob/588e61006bb606d08cc981467d7990c6e3104c42/README.md
rgbwalker V1.2 fabrication archive:
https://github.com/rgbwalker/Amstrad_CPC_464_new_Cherry_Keyboard/blob/588e61006bb606d08cc981467d7990c6e3104c42/_GERBER_V1.2_/Gerber_Amstrad_Teclado_09_PCB_Amstrad_Te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
Pico physical header reference:
https://datasheets.raspberrypi.com/pico/Pico-R3-A4-Pinout.pdf

The PDF uses original vector drawings; it includes no copied PCB photos.
Regenerate both sheets:
  python3 -m pip install -r scripts/requirements-docs.txt
  python3 scripts/generate_pinout.py

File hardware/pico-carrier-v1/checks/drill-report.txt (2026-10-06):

Drill report for goodjohn-carrier.kicad_pcb
Created on 2026-10-06T11:56:40

Copper Layer Stackup:
    =============================================================
    L1 :  F.Cu                      front
    L2 :  B.Cu                      back

Drill file 'goodjohn-carrier-PTH.drl' contains
    plated through holes:
    =============================================================
    T1  0.400mm  0.0157"  (13 holes))
    T2  1.000mm  0.0394"  (79 holes))

    Total plated holes count 92

Drill file 'goodjohn-carrier-NPTH.drl' contains
    unplated through holes:
    =============================================================
    T1  3.200mm  0.1260"  (4 holes))

    Total unplated holes count 4

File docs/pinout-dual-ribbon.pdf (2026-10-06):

Revision 2 / 2026-10-06 | Bread80 J1 CPC464 | Not bench-tested | 1

# Two 10-pin ribbons to Pico

Bread80 CPC464 SMT / keyboard J1 / CPC464 link setting.
Original RP2040 Pico or Pico H. Source-checked; this harness has not been bench-tested.

USB keyboard use only. Physically disconnect the keyboard from the CPC motherboard, even when powered off. No simultaneous CPC/PC keyboard operation or pass-through mode. Switching the CPC off is not enough.

Unplug USB before wiring. Bridge LK1 pads 1-2 only and LK2 pads 1-2. Leave LK3 and LK4-LK6 open.

Ribbon A = odd J1 pads; ribbon B = even J1 pads. A/B are guide labels. Count both ribbons from the square J1 pad 1 end. Nineteen signals; no matrix power or ground wire.

Ribbon pos. | J1 PCB pad | Net | Pico GPIO | Pico PHYSICAL pin
A1 | 1 | Y10 | GP11 | 15
A2 | 3 | X1 | GP12 | 16
A3 | 5 | X2 | GP13 | 17
A4 | 7 | X3 | GP14 | 19
A5 | 9 | X4 | GP15 | 20
A6 | 11 | X5 | GP16 | 21
A7 | 13 | X6 | GP17 | 22
A8 | 15 | X7 | GP18 | 24
A9 | 17 | X9 | GP20 | 26
A10 | 19 | NC | -- | Leave disconnected
B1 | 2 | X8 | GP19 | 25
B2 | 4 | Y9 | GP10 | 14
B3 | 6 | Y8 | GP9 | 12
B4 | 8 | Y7 | GP8 | 11
B5 | 10 | Y6 | GP7 | 10
B6 | 12 | Y5 | GP6 | 9
B7 | 14 | Y4 | GP5 | 7
B8 | 16 | Y3 | GP4 | 6
B9 | 18 | Y2 | GP3 | 5
B10 | 20 | Y1 | GP2 | 4

A10 / J1 pad 19 is unused. B10 / J1 pad 20 must connect to Y1. GPIO numbers differ from physical pins. On the Pico component side, USB at top: physical 1-20 run down the left, 21-40 up the right.

The existing firmware GPIO assignments and keymap apply. Keep diode option OFF for initial testing; ON can be used once all switch diodes are fitted and verified.

Scope: this is the keyboard's J1, not the adapter J1 in the original 19-pin drawing. CPC6128 settings, J2 modular, Tactile J2/J3 and unverified original membrane tails need separate mappings.

Revision 2 / 2026-10-06 | Bread80 J1 CPC464 | Not bench-tested | 2

# Orientation and electrical checks

KEYBOARD COMPONENT SIDE / KEYS FACING YOU
Rear / Esc end
Ribbon B | Ribbon A
B1 ( 2) | [ 1] A1 square pad
B2 ( 4) | ( 3) A2
B3 ( 6) | ( 5) A3
B4 ( 8) | ( 7) A4
B5 (10) | ( 9) A5
B6 (12) | (11) A6
B7 (14) | (13) A7
B8 (16) | (15) A8
B9 (18) | (17) A9
B10 (20) | (19) A10 -- no connection
| Space-bar end
Parenthesized numbers are Bread80 J1 PCB pad numbers.
Solder-side view is mirrored. The schematic's original CPC labels 1-10 / 11-20 differ from its odd/even J1 pad numbers. Verify the square pad and every cable endpoint.

## Link checks and first USB test

With USB unplugged, J1.1 to J3.2 (Y10) and J1.2 to J3.10 (X8) must each conduct without a key pressed. X8 (J3.10) and X9 (J3.1) must remain separate. LK1 pad 1 is square; its third pad remains open.

Start with A2 / J1.3 to Pico physical 16 and B2 / J1.4 to physical 14. Check each wire, connect USB, then test top-row
1. Unplug USB between changes: add A3 / J1.5 to physical 17 for 2, and A4 / J1.7 to physical 19 for Esc. Complete the harness and test each key.

Switch checks: keyboard disconnected from both Pico and CPC. Use diode mode, red on X, black on Y. Pressed conducts; released is open. The Pico column identifies the eventual harness endpoints.

Key held | Ribbon X / Y | J1 pads X / Y | Pico physical X / Y
Top-row 1 | A2 / B2 | 3 / 4 | 16 / 14
Top-row 2 | A3 / B2 | 5 / 4 | 17 / 14
Esc | A4 / B2 | 7 / 4 | 19 / 14
Space | B1 / B5 | 2 / 10 | 25 / 10
Either Shift | A7 / B8 | 13 / 16 | 22 / 6
DEL (Backspace) | A9 / A1 | 17 / 1 | 26 / 15
Main Enter | A4 / B8 | 7 / 16 | 19 / 6
Cursor Up | A2 / B10 | 3 / 20 | 16 / 4

Sources: Bread80 PCB (https://github.com/Bread80/CPC_Keyboards/blob/bf4a6052888fef27ca01a6b0983791d7cb4e8af1/Keyswitch_CPC464_SMT/Keyboard.kicad_pcb) and schematic, (https://github.com/Bread80/CPC_Keyboards/blob/bf4a6052888fef27ca01a6b0983791d7cb4e8af1/Keyswitch_CPC464_SMT/Keyboard.kicad_sch) revision bf4a6052888fef27ca01a6b0983791d7cb4e8af1. GPIO assignments: src/board_config.h.

Full notes: docs/wiring-dual-ribbon.md. Vector diagram: docs/wiring-dual-ribbon.svg. Regenerate all companions with python3 scripts/generate_dual_ribbon.py.

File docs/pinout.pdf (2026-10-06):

GOODJOHN / WORKBENCH REFERENCE

# Keyboard-to-Pico wire list

Bread80 CPC464 SMT / J3 19-pin connector / original RP2040 Pico or Pico H

Revision 5 / 2026-10-06 | V1.2 basic typing passed; further tests pending | 1 / 4

USB keyboard use only. Physically disconnect the keyboard from the CPC motherboard, even when off. No simultaneous CPC/PC keyboard operation. Use 19 signal wires only; no matrix power or ground. Power the Pico by USB.

Keyboard J3 | Pico GPIO | PC USB port
J3 pad | Matrix net | Pico GPIO | Pico header pin | Signal role
01 | X9 | GP20 | 26 | Sense input
02 | Y10 | GP11 | 15 | Scan output
03 | X1 | GP12 | 16 | Sense input
04 | X2 | GP13 | 17 | Sense input
05 | X3 | GP14 | 19 | Sense input
06 | X4 | GP15 | 20 | Sense input
07 | X5 | GP16 | 21 | Sense input
08 | X6 | GP17 | 22 | Sense input
09 | X7 | GP18 | 24 | Sense input
10 | X8 | GP19 | 25 | Sense input
11 | Y9 | GP10 | 14 | Scan output
12 | Y8 | GP9 | 12 | Scan output
13 | Y7 | GP8 | 11 | Scan output
14 | Y6 | GP7 | 10 | Scan output
15 | Y5 | GP6 | 09 | Scan output
16 | Y4 | GP5 | 07 | Scan output
17 | Y3 | GP4 | 06 | Scan output
18 | Y2 | GP3 | 05 | Scan output
19 | Y1 | GP2 | 04 | Scan output

Header pin is the physical pin number. For example, J3 pad 1 connects to GP20 on Pico pin 26, not to Pico pin 20.

## Identify J3 before wiring

With keys facing you and cursor keys at upper right, J3 is the single vertical row at the keyboard's far left. On the inspected PCB, pad 1 is square at the Esc end; pad 19 is at the Caps end. The solder-side view is mirrored.

Leave LK1, LK2, LK3 and LK4-LK6 open for this prototype. LK3 joins X8/X9; the last three links serve the unused bonus keys. J1 and J2 have different pin orders.

J3 nets: Bread80 PCB revision bf4a6052888f. Firmware pin assignments: src/board_config.h. See page 4 for rgbwalker V1.2 checks and the first hardware test.

# Pico header orientation

Top view: components and BOOTSEL button facing you, USB connector at the top. Not to scale.

Revision 5 / 2026-10-06 | V1.2 basic typing passed; further tests pending | 2 / 4

Numbers beside the board are physical header pins. Labels show GPIO / matrix net / J3 pad. Anything marked unused stays unconnected in this keyboard harness.

USB to PC

BOOTSEL

RP2040

Pico / Pico H

GP0 | unused | 01 | 40 | VBUS unused
GP1 | unused | 02 | 39 | VSYS unused
GND | unused | 03 | 38 | GND | unused
GP2 Y1 J3 19 | 04 | 37 | 3V3_EN unused
GP3 Y2 J3 18 | 05 | 36 | 3V3(OUT) unused
GP4 Y3 J3 17 | 06 | 35 | ADC_VREF unused
GP5 Y4 J3 16 | 07 | 34 | GP28 unused
GND | unused | 08 | 33 | AGND unused
GP6 Y5 J3 15 | 09 | 32 | GP27 unused
GP7 Y6 J3 14 | 10 | 31 | GP26 unused
GP8 Y7 J3 13 | 11 | 30 | RUN | unused
GP9 Y8 J3 12 | 12 | 29 | GP22 unused
GND | unused | 13 | 28 | GND | unused
GP10 Y9 J3 11 | 14 | 27 | GP21 unused
GP11 Y10 J3 02 | 15 | 26 | GP20 X9 J3 01
GP12 X1 J3 03 | 16 | 25 | GP19 X8 J3 10
GP13 X2 J3 04 | 17 | 24 | GP18 X7 J3 09
GND | unused | 18 | 23 | GND | unused
GP14 X3 J3 05 | 19 | 22 | GP17 X6 J3 08
GP15 X4 J3 06 | 20 | 21 | GP16 X5 J3 07

Y = scan outputs X = sense inputs Grey = unused

## Three details that prevent wiring mistakes

Count down the left side: 1 to 20. The right side counts up from 21 at the bottom to 40 at the top. Ground pins interrupt the GPIO sequence.

No matrix supply pin: X inputs use the Pico's internal 3.3 V pull-ups. The USB cable powers the Pico; the passive keyboard needs only the 19 signal connections.

Do not join X8 and X9 in this harness. X9 is dedicated to DEL. Both Shift switches share Y3/X6 and cannot be distinguished by firmware.

Physical numbering checked against Raspberry Pi's official Pico pinout PDF. (https://datasheets.raspberrypi.com/pico/Pico-R3-A4-Pinout.pdf) The diagram above is an original drawing for this project.

# Assemble and verify

Work with USB unplugged during wiring and meter checks. Connect only the passive keyboard.

Revision 5 / 2026-10-06 | V1.2 basic typing passed; further tests pending | 3 / 4
1. Prepare: identify the exact board and J3 pad 1. Open LK1-LK6. Fit Pico headers if needed. Use insulated wires or a labeled breakout harness; keep the first cable short.
2. Wire: follow page 1 one contact at a time. Check every cable endpoint and look for unintended adjacent shorts. Do not rely on ribbon-wire colors or a mirrored photograph.
3. Test contacts: disconnect the keyboard from both Pico and CPC; check the pairs below. On a diode board, place the red meter probe on X and black on Y, using diode mode.
Key held | Y / X nets | J3 pads | Pico header pins
Cursor Up | Y1 / X1 | 19 / 3 | 4 / 16
A | Y9 / X6 | 11 / 8 | 14 / 22
Space | Y6 / X8 | 14 / 10 | 10 / 25
Either Shift | Y3 / X6 | 17 / 8 | 6 / 22
DEL | Y10 / X9 | 2 / 1 | 15 / 26
Main Enter | Y3 / X3 | 17 / 5 | 6 / 19
Keypad Enter | Y1 / X7 | 19 / 9 | 4 / 24

A pressed key should conduct; releasing it should open the path. A diode blocks the reverse direction. A plain switch conducts either way. A continuity beeper may not detect the diode path reliably.

Current path: internal 3.3 V pull-up → X → closed switch → diode → selected Y.
Diode cathode faces Y. Only the selected Y is driven low; inactive Y pins float.

## Choose the correct scan option

Bread80 SMT, all diodes verified: set the option ON. rgbwalker, membrane, tactile, or uncertain diodes: keep it OFF. These commands assume the SDK build is already configured; see README.md for initial setup.

cmake -S . -B build -DGOODJOHN_MATRIX_HAS_DIODES=ON
cmake --build build --parallel
Use OFF instead of ON for a matrix without verified diodes.

## Flash, then test on the PC

Hold BOOTSEL while connecting the Pico, then copy build/goodjohn.uf2 to RPI-RP2. Use a USB data cable. Check every key and release, modifiers, DEL and both Enter keys. COPY sends Alt; DEL sends Backspace; CLR sends forward Delete. Set the PC's Num Lock for keypad digits.

If one group of keys fails, recheck its X/Y wire and diode orientation. If only chords fail on a board without diodes, ghost suppression may be blocking ambiguity. More than six regular keys produces HID ErrorRollOver. Shifted symbols follow the PC layout; there is no Fn layer yet.

V1.2 digits, all letter rows, Esc and main Enter passed with the completed direct harness; see page 4. Remaining keys, chords, cable settling, USB reconnect and suspend still need tests. No USB remote wakeup or low-power suspend implementation is provided yet.

# Other boards and source notes

The logical CPC key matrix is shared; connector order and jumper routing are not universal.

Revision 5 / 2026-10-06 | V1.2 basic typing passed; further tests pending | 4 / 4

rgbwalker V1.2: basic typing passed (2026-10-06). User confirmed digits, all letter rows, Esc and main Enter with the completed 19-wire direct harness.

V1.2 Gerbers connect CP002_THT and CP002_SMD contacts 1-19 in the same order; contact 20 is isolated from the matrix. Count the square pad as 1 at the Esc end, toward Shift. Check other revisions separately.

Expected contact(s) | Expected switch lines | Pico harness, if confirmed
1 and 2 | Isolated DEL switch | GP20 and GP11
3 through 10 | X1 through X8 | GP12 through GP19
11 through 19 | Y9 through Y1 | GP10 down through GP2
20 | No matrix connection (V1.2) | Leave isolated

Start directly: keyboard 3 to Pico physical 16 (GP12); keyboard 11 to physical 14 (GP10). With USB unplugged, each wire must beep pad-to-pad without a key held. Connect USB: top-row 1 should type 1. Bypassing the earlier ribbon/jumper assembly restored this; its exact fault is unresolved.

Unplug USB, then add 4 to physical 17 (GP13) for 2; next 5 to physical 19 (GP14) for Esc. Check each wire before power. Esc prints no character. Complete contacts 1-19 using page 1, leave 20 disconnected, and keep GOODJOHN_MATRIX_HAS_DIODES=OFF. Details: docs/wiring.md.

## Bread80 alternatives

J1 membrane, CPC464 links: see the separate docs/pinout-dual-ribbon.pdf and wiring-dual-ribbon.svg. J2 modular: not mapped here. Tactile: different connectors, no diodes. CPC6128 SMT: design-stage board; not a validated adapter target.

An 18-wire adaptation must handle the shared X8/X9 net explicitly; simply omitting X9 loses DEL.

## Source records

Bread80 CPC464 SMT KiCad PCB (https://github.com/Bread80/CPC_Keyboards/blob/bf4a6052888fef27ca01a6b0983791d7cb4e8af1/Keyswitch_CPC464_SMT/Keyboard.kicad_pcb)
Revision bf4a6052888fef27ca01a6b0983791d7cb4e8af1. J3 pad nets, square pad 1, connector placement, diode cathodes and switch coordinates were inspected.

rgbwalker V1.2 fabrication archive (https://github.com/rgbwalker/Amstrad_CPC_464_new_Cherry_Keyboard/blob/588e61006bb606d08cc981467d7990c6e3104c42/_GERBER_V1.2_/Gerber_Amstrad_Teclado_09_PCB_Ams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)
Revision 588e61006bb606d08cc981467d7990c6e3104c42. Copper/plated-hole tracing checks THT/SMD correspondence, unused contact 20, and switch pairs: 1 = 3/11, 2 = 4/11, Esc = 5/11.

Raspberry Pi official Pico pinout (https://datasheets.raspberrypi.com/pico/Pico-R3-A4-Pinout.pdf)
Pico-R3-A4-Pinout.pdf. Used to check the 40 physical header positions and power/ground labels. Target is the original non-wireless RP2040 Pico/Pico H.

## Files and regeneration

The companion ASCII sheet is docs/pinout.txt. The generator reads the firmware GPIO arrays in src/board_config.h and produces both formats from one wiring dataset. These are original vector drawings, not scaled PCB templates.

python3 -m pip install -r scripts/requirements-docs.txt
python3 scripts/generate_pinout.py

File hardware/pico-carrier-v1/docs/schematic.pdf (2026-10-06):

1 | 2 | 3 | 4 | 5 | 6
1 | 2 | 3 | 4 | 5 | 6

AB

C

D

AB

C

## D Date: 2026-10-06

Size: A4 | Rev: 1.0-prototype
KiCad E.D.A. 10.0.6 | Id: 1/1

# Title: Goodjohn - CPC464 USB keyboard carrier

## File: goodjohn-carrier.kicad_sch

## Sheet: /

## salvogendut / Goodjohn

## RP2040 Pico only - USB keyboard use only

## Disconnect keyboard from CPC motherboard, even when CPC is off 1

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
J3RIBBON_B_EVEN

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
# 9/10 J2RIBBON_A_ODD

GPIO0 1 | GPIO1 2 | GND

3 GPIO2 4 GPIO3 5 GPIO4 6 GPIO5 7 GPIO6 9 GPIO7 10 GPIO8 11 GPIO9 12 GPIO10 14 GPIO11 15 GPIO12 16 GPIO13 17 GPIO14 19 GPIO15 20 GPIO16 21 GPIO17 22 GPIO18 24 GPIO19 25 GPIO20 26 GPIO21 27 GPIO22 29 RUN 30 GPIO26_ADC0 31 GPIO27_ADC1 32

AGND | 33 GPIO28_ADC2 | 34
ADC_VREF | 35 3V3 36
3V3_EN 37 | VSYS 39 | VBUS U1 | 40 | RaspberryPi_Pico | H2M3_NPTH

H1M3_NPTH

H3M3_NPTH

H4M3_NPTH

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
# 18/19 J1CPC464_INLINE_19

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
Y6 GND | Y1

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
Y3 U1: original RP2040 Pico / Pico H on two 1x20 sockets. PC USB data cable supplies power via the Pico USB socket. Only GND is used on the carrier; VBUS / VSYS / 3V3 stay isolated. GP2..GP11 scan Y1..Y10; GP12..GP20 sense X1..X9. Unselected rows are inputs; X inputs use Pico pull-ups. H1..H4: 3.2mm unplated holes for M3 standoffs. All keyboard contacts are signals: never attach power or GND. Prototype: electrical/design checks do not replace bench testing.

J1: INLINE 19 CONTACTS

rgbwalker V1.2 / Bread80 J3 / original PCB-style CPC464 Contact 1 = X9; optional keyboard contact 20 stays unused. Use J1 OR J2 + J3 for one keyboard. No CPC pass-through; no keyboard supply connection. | BREAD80 CPC464 SMT J1
J2 = A, | odd keyboard pads 1..19
J3 = B, | even keyboard pads 2..20

A10 / keyboard J1.19 is NC. B10 / keyboard J1.20 is Y1. LK1: 1-2; LK2: 1-2; LK3 open. Bonus links open. GOODJOHN / CPC464 USB KEYBOARD CARRIER

USB KEYBOARD ONLY - DISCONNECT CPC MOTHERBOARD, EVEN WHEN POWERED OFF.

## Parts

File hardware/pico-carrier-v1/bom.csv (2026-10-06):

Reference | Quantity | Item | Specification | Notes
PCB | 1 | Goodjohn carrier v1 | 80 x 66 mm; 2 layers; 1.6mm FR4; 1oz copper | Unbuilt prototype
U1 | 1 | Raspberry Pi Pico / Pico H | Original RP2040; male headers pointing down | USB faces upper edge
U1 sockets | 2 | Female header 1x20 | 2.54mm pitch; 17.78mm row spacing; nominal 8.5mm body height | Match chosen male headers; sockets fitted to carrier
J1 | 1 | Male header 1x19 | 2.54mm pitch; vertical; 0.64mm square posts | Optional for ribbon-only build
J2 J3 | 2 | Male header 1x10 | 2.54mm pitch; vertical; 0.64mm square posts | Optional for inline-only build
H1-H4 | 4 | M3 standoff/screw sets | 3.2mm NPTH; head/washer envelope <=7mm | Optional; protect underside from metalwork
USB cable | 1 | USB data cable | PC host to Pico Micro-USB | Power and data on one cable
Keyboard harness | 1 | Mating 2.54mm harness | Inline 19 OR separate A/B 10-way cables | Verify every contact; bare membrane tails need adapter

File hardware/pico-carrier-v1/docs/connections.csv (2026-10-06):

Carrier reference | Carrier contact | Matrix net | Pico GPIO | Pico physical pin | Keyboard connector | Keyboard contact
J1 | 1 | X9 | GP20 | 26 | Inline 19 | 1
J1 | 2 | Y10 | GP11 | 15 | Inline 19 | 2
J1 | 3 | X1 | GP12 | 16 | Inline 19 | 3
J1 | 4 | X2 | GP13 | 17 | Inline 19 | 4
J1 | 5 | X3 | GP14 | 19 | Inline 19 | 5
J1 | 6 | X4 | GP15 | 20 | Inline 19 | 6
J1 | 7 | X5 | GP16 | 21 | Inline 19 | 7
J1 | 8 | X6 | GP17 | 22 | Inline 19 | 8
J1 | 9 | X7 | GP18 | 24 | Inline 19 | 9
J1 | 10 | X8 | GP19 | 25 | Inline 19 | 10
J1 | 11 | Y9 | GP10 | 14 | Inline 19 | 11
J1 | 12 | Y8 | GP9 | 12 | Inline 19 | 12
J1 | 13 | Y7 | GP8 | 11 | Inline 19 | 13
J1 | 14 | Y6 | GP7 | 10 | Inline 19 | 14
J1 | 15 | Y5 | GP6 | 9 | Inline 19 | 15
J1 | 16 | Y4 | GP5 | 7 | Inline 19 | 16
J1 | 17 | Y3 | GP4 | 6 | Inline 19 | 17
J1 | 18 | Y2 | GP3 | 5 | Inline 19 | 18
J1 | 19 | Y1 | GP2 | 4 | Inline 19 | 19
J2 | 1 | Y10 | GP11 | 15 | Bread80 CPC464 SMT J1 | 1
J2 | 2 | X1 | GP12 | 16 | Bread80 CPC464 SMT J1 | 3
J2 | 3 | X2 | GP13 | 17 | Bread80 CPC464 SMT J1 | 5
J2 | 4 | X3 | GP14 | 19 | Bread80 CPC464 SMT J1 | 7
J2 | 5 | X4 | GP15 | 20 | Bread80 CPC464 SMT J1 | 9
J2 | 6 | X5 | GP16 | 21 | Bread80 CPC464 SMT J1 | 11
J2 | 7 | X6 | GP17 | 22 | Bread80 CPC464 SMT J1 | 13
J2 | 8 | X7 | GP18 | 24 | Bread80 CPC464 SMT J1 | 15
J2 | 9 | X9 | GP20 | 26 | Bread80 CPC464 SMT J1 | 17
J2 | 10 | NC |  |  | Bread80 CPC464 SMT J1 | 19
J3 | 1 | X8 | GP19 | 25 | Bread80 CPC464 SMT J1 | 2
J3 | 2 | Y9 | GP10 | 14 | Bread80 CPC464 SMT J1 | 4
J3 | 3 | Y8 | GP9 | 12 | Bread80 CPC464 SMT J1 | 6
J3 | 4 | Y7 | GP8 | 11 | Bread80 CPC464 SMT J1 | 8
J3 | 5 | Y6 | GP7 | 10 | Bread80 CPC464 SMT J1 | 10
J3 | 6 | Y5 | GP6 | 9 | Bread80 CPC464 SMT J1 | 12
J3 | 7 | Y4 | GP5 | 7 | Bread80 CPC464 SMT J1 | 14
J3 | 8 | Y3 | GP4 | 6 | Bread80 CPC464 SMT J1 | 16
J3 | 9 | Y2 | GP3 | 5 | Bread80 CPC464 SMT J1 | 18
J3 | 10 | Y1 | GP2 | 4 | Bread80 CPC464 SMT J1 | 20

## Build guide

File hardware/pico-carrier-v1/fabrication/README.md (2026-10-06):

# Prototype fabrication files

`goodjohn-carrier-v1-gerbers.zip` contains the seven Gerber layers, two Excellon
drill files and the Gerber job file in [gerbers/](gerbers). These were exported
from the routed, zone-filled KiCad PCB after a clean DRC/parity check.

| Parameter | Value |
| --- | --- |
| Outline | 80 × 66 mm; single rectangular board |
| Stack | 2 copper layers; 1.6 mm FR4; 35 µm / 1 oz copper |
| Tracks | 0.30 mm; project minimum 0.25 mm |
| Copper clearance | Project minimum 0.25 mm; routing target 0.30 mm |
| Copper to board edge | Minimum 0.50 mm |
| Vias | 13 × 0.80 mm diameter / 0.40 mm finished drill; tent both sides |
| Component plated holes | 79 × 1.00 mm |
| Mounting holes | 4 × 3.20 mm **non-plated** |
| Solder mask / legend | Both sides; green mask / white legend suggested |
| Finish | Lead-free HASL or ENIG; no controlled impedance requirement |
| Assembly | Hand soldering; no stencil or pick-and-place file needed |

All Gerber and drill files use the same absolute origin, metric units and no
mirroring. The board starts at KiCad coordinates (100,100) mm; do not realign
individual layers. `Edge_Cuts.gm1` is the single routed outline. There are no
slots, milling cutouts or inner copper layers. Do not add copper plating to
the four mounting holes.

Outline dimensions refer to the centreline of its 0.05 mm drawing stroke.
KiCad's Gerber job bounding box includes that stroke and reports 80.05 × 66.05 mm;
the four outline corner coordinates define the intended **80 × 66 mm** board.
The [export check](../checks/fabrication.json) compares all 92 plated and four
unplated drill locations/diameters to the final PCB and checks the profile corners.

| Extension | Layer |
| --- | --- |
| `.gtl`, `.gbl` | Front / back copper |
| `.gts`, `.gbs` | Front / back solder mask openings |
| `.gto`, `.gbo` | Front / back silkscreen |
| `.gm1` | Board outline |
| `-PTH.drl` | Plated component holes and vias |
| `-NPTH.drl` | Four unplated mounting holes |

Check the manufacturer's layer preview, dimensions and NPTH interpretation
before ordering. This is an **unbuilt prototype**; first-board assembly and
bench testing remain pending. No fabrication order has been placed.

[SHA256SUMS.txt](SHA256SUMS.txt) records the design, reports and individual
fabrication files used for this export. Check from the carrier directory with
`sha256sum -c fabrication/SHA256SUMS.txt`.

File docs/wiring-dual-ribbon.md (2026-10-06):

# Bread80 CPC464 SMT: two 10-pin ribbons to Pico

Revision 2 / 2026-10-06. **Source-checked; this J1 harness has not been bench-tested.**
The rgbwalker J3-style harness has its own [hardware test record](wiring.md#hardware-test-record-2026-10-06).

> [!WARNING]
> **USB keyboard use only.** Physically disconnect the keyboard from the CPC
> motherboard, even when the CPC is powered off. **The keyboard cannot operate
> the CPC and PC simultaneously.** There is no pass-through mode; switching the
> CPC off is not enough.

Two-ribbon J1 wiring to Raspberry Pi Pico

Companions: [ASCII pinout](pinout-dual-ribbon.txt) and [two-page PDF](pinout-dual-ribbon.pdf).

## Exact target and link settings

This scheme is for **Bread80 `Keyswitch_CPC464_SMT`, keyboard connector J1
(Membrane 464/6128), configured for CPC464**, at revision `bf4a6052888fef27ca01a6b0983791d7cb4e8af1`.
J1 has two columns of ten contacts for two 10-way ribbons. These are nineteen
matrix signals plus one unused contact; no matrix power or ground wire is needed.
The Pico is an original RP2040 Pico / Pico H, powered by its USB data connection
to the PC. Disconnect the keyboard from the CPC motherboard entirely.

With USB unplugged, configure the **keyboard PCB** links:

| Link | Required state | Electrical effect |
| --- | --- | --- |
| LK1 | Bridge pads **1-2** only (CPC464 end); pad 3 remains open | J1 pad 2 / B1 connects to X8 |
| LK2 | Bridge pads **1-2** | J1 pad 1 / A1 connects to Y10 |
| LK3 | **Open** | X8 and X9 remain separate |
| LK4, LK5, LK6 | **Open** for initial testing | Bonus switches remain disconnected |

LK1 pad 1 is the square pad on that link. Use pad numbers and verify with a
meter; upstream text/silkscreen contains inconsistent JP/LK references. The
net connections above were checked in the PCB and schematic.

The existing firmware GPIO assignments and keymap apply to this harness.
The conservative diode option OFF can be kept for initial testing. If every
switch diode is fitted and its orientation verified, setting
`GOODJOHN_MATRIX_HAS_DIODES=ON` permits chords that the default ghost filter
would otherwise suppress. No connector-specific firmware remapping is needed.

This table does not cover the CPC6128 link setting, Bread80's J2 modular
connector, the Tactile board's J2/J3, or an original membrane tail whose contact
order has not been verified. On this sheet **J1 means the keyboard connector**;
the J1 in the original [19-pin SVG](wiring.svg) names a proposed adapter instead.

## Connector orientation and numbering

```text
       KEYBOARD COMPONENT SIDE / KEYS FACING YOU
                    Rear / Esc end

           Ribbon B             Ribbon A
              B1 ( 2)          [ 1] A1  square pad
              B2 ( 4)          ( 3) A2
              B3 ( 6)          ( 5) A3
              B4 ( 8)          ( 7) A4
              B5 (10)          ( 9) A5
              B6 (12)          (11) A6
              B7 (14)          (13) A7
              B8 (16)          (15) A8
              B9 (18)          (17) A9
             B10 (20)          (19) A10 -- no connection

                    Space-bar end
       Parenthesized numbers are Bread80 J1 PCB pad numbers.
```

**A and B are labels defined by this guide**, not additional PCB references.
Count A1 and B1 from the same end, next to square J1 pad 1. Ribbon A uses the
**odd** J1 pads; ribbon B uses the **even** pads. A10 is J1 pad **19** and stays
disconnected. B10 is J1 pad **20** and is required for Y1.

Bread80's schematic labels the A ends as original CPC pins 1/10 and the B ends
as 11/20. Those are not the KiCad J1 pad numbers. This guide always distinguishes
ribbon position, J1 PCB pad number, GPIO number and Pico physical pin number.
The solder-side view is mirrored; identify square pad 1 on the actual board.
Check cable continuity even when both ends use identical housings or colors.

## Complete wiring scheme

| Ribbon position | J1 PCB pad | Net | Pico GPIO | Pico physical pin |
| --- | --- | --- | --- | --- |
| A1 | 1 | Y10 | GP11 | 15 |
| A2 | 3 | X1 | GP12 | 16 |
| A3 | 5 | X2 | GP13 | 17 |
| A4 | 7 | X3 | GP14 | 19 |
| A5 | 9 | X4 | GP15 | 20 |
| A6 | 11 | X5 | GP16 | 21 |
| A7 | 13 | X6 | GP17 | 22 |
| A8 | 15 | X7 | GP18 | 24 |
| A9 | 17 | X9 | GP20 | 26 |
| A10 | 19 | NC | -- | Leave disconnected |
| B1 | 2 | X8 | GP19 | 25 |
| B2 | 4 | Y9 | GP10 | 14 |
| B3 | 6 | Y8 | GP9 | 12 |
| B4 | 8 | Y7 | GP8 | 11 |
| B5 | 10 | Y6 | GP7 | 10 |
| B6 | 12 | Y5 | GP6 | 9 |
| B7 | 14 | Y4 | GP5 | 7 |
| B8 | 16 | Y3 | GP4 | 6 |
| B9 | 18 | Y2 | GP3 | 5 |
| B10 | 20 | Y1 | GP2 | 4 |

Only GP2 through GP20 are used. All other Pico header pins stay unconnected
to the keyboard. On a Pico viewed component-side up with USB at the top, physical
pins 1-20 run down the left, and 21-40 run up the right.

## Continuity and staged power-up

1. Disconnect USB and the CPC motherboard. Fit the links above.
2. Verify J1.1 to Y10 (also J3.2), and J1.2 to X8 (also J3.10), each near zero
   ohms without a key held. Verify X8 (J3.10) and X9 (J3.1) are not shorted.
3. Connect A2 / J1.3 to Pico physical 16, and B2 / J1.4 to physical 14. Check
   both individual wires pad-to-pad without holding a key, then connect USB.
   Press top-row `1`; it should type `1`.
4. Unplug USB, add A3 / J1.5 to physical 17, then test `2`. Next add A4 / J1.7
   to physical 19 for Esc. Esc does not print a character.
5. Complete the remaining connections, checking each wire before power-up.
   Test digits, letters, modifiers, both Enter keys, cursor/keypad keys and DEL.
   Test Space and DEL separately to check X8 and the isolated X9/Y10 path.

For switch-pair checks, disconnect the keyboard from the Pico as well. On the
diode board, use diode mode: red probe on X and black probe on Y. Pressed should
conduct in that direction; released should be open. A continuity beeper may not
detect a diode reliably. The Pico pin column below identifies the harness
endpoints; perform these switch-identification measurements on the detached keyboard.

| Key held | Ribbon pair (X / Y) | J1 pads | Pico physical pins |
| --- | --- | --- | --- |
| Top-row 1 | A2 / B2 | 3 / 4 | 16 / 14 |
| Top-row 2 | A3 / B2 | 5 / 4 | 17 / 14 |
| Esc | A4 / B2 | 7 / 4 | 19 / 14 |
| Space | B1 / B5 | 2 / 10 | 25 / 10 |
| Either Shift | A7 / B8 | 13 / 16 | 22 / 6 |
| DEL (Backspace) | A9 / A1 | 17 / 1 | 26 / 15 |
| Main Enter | A4 / B8 | 7 / 16 | 19 / 6 |
| Cursor Up | A2 / B10 | 3 / 20 | 16 / 4 |

## Sources and regeneration

- [Bread80 PCB at the inspected revision](https://github.com/Bread80/CPC_Keyboards/blob/bf4a6052888fef27ca01a6b0983791d7cb4e8af1/Keyswitch_CPC464_SMT/Keyboard.kicad_pcb): J1 pads, connector orientation and LK1-LK6 nets.
- [Matching schematic](https://github.com/Bread80/CPC_Keyboards/blob/bf4a6052888fef27ca01a6b0983791d7cb4e8af1/Keyswitch_CPC464_SMT/Keyboard.kicad_sch): CPC464/CPC6128 routing, ribbon numbering and matrix switch paths.
- `src/board_config.h`: GPIO assignments, shared with the existing firmware.

Install `scripts/requirements-docs.txt`, then run:

```sh
python3 scripts/generate_dual_ribbon.py
```

The generator creates this Markdown scheme, the ASCII/PDF sheets and the SVG
from one connector dataset. Pico vector artwork comes from `pico-pinout.svg`.

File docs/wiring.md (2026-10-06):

# Prototype wiring

This is a wiring proposal checked against source files, **not a bench-validated
schematic or an interface PCB ready for manufacture**. GPIO numbers below are
for the original non-wireless RP2040 Raspberry Pi Pico. On 2026-10-06, the user
confirmed digits, all letter rows, Esc and main Enter on rgbwalker V1.2 with a
completed 19-wire direct harness. Further key/chord and USB tests remain pending.

Printable companions: [ASCII pinout](pinout.txt) and [detailed PDF](pinout.pdf).
The [SVG wiring overview](wiring.svg) shows the Pico and a proposed J1 adapter
connector with the same contact numbering as the keyboard's J3. It is a wiring
guide, not a PCB layout; J1 contact 1 is drawn at the bottom and crossings are
not electrical junctions.
The PDF includes all 40 Pico header positions, the 19-wire J3 harness and
unpowered switch checks. It distinguishes the source-checked J3 mapping from
the rgbwalker V1.2 connector checks and initial hardware test.

**USB keyboard use only: the keyboard cannot operate the CPC and PC at the same
time.** Physically disconnect it from the CPC motherboard, including when that
motherboard is powered off. There is no simultaneous-use or pass-through mode;
switching the CPC off is not enough. This firmware drives the matrix and is not
a passive sniffer. The Pico GPIO interface is 3.3 V; do not connect
CPC 5 V logic or USB VBUS to a matrix pin. The passive switch matrix does not
need a VCC supply. Power the Pico through its USB connector.

## Physical matrix

The firmware follows Bread80's net names: rows `Y1..Y10` and columns `X1..X9`.
Indices in the C arrays are zero based. Most keys occupy Y1..Y9 by X1..X8;
DEL occupies Y10/X9. The familiar CPC logical 10-by-8 scan hides the separate
DEL sense wire by joining X8 and X9 on the computer side. The standalone Pico
prototype preserves both wires, using 19 GPIOs.

Both Shift switches occupy Y3/X6. Software cannot tell them apart. The optional
Bread80 bonus keys can be connected to Y10/X5 and Y10/X6 by its links, but those
positions are currently unmapped in the firmware.

For the diode board, the PCB connects diode pad 1 (cathode) to Y and the switch
side to X through pad 2 (anode). The scan therefore pulls one Y low and reads
X inputs with 3.3 V pull-ups. All other Y pins remain high impedance. This also
avoids opposing GPIO outputs through simultaneous presses on boards without
diodes. No matrix output is driven high.

## Bread80 CPC464 SMT: J3 inline connector

This table comes from pad nets in
`../CPC_Keyboards/Keyswitch_CPC464_SMT/Keyboard.kicad_pcb` at revision
`bf4a6052888fef27ca01a6b0983791d7cb4e8af1`.
J3 is a **19-pin** footprint in this source revision. Numbers refer to KiCad
pad numbers, not left-to-right appearance in a photograph. Locate pad 1 on the
actual board and verify continuity before connecting the Pico.

| Matrix net | J3 pad | Pico GPIO | Pico physical header pin |
| --- | ---: | ---: | ---: |
| Y1 | 19 | 2 | 4 |
| Y2 | 18 | 3 | 5 |
| Y3 | 17 | 4 | 6 |
| Y4 | 16 | 5 | 7 |
| Y5 | 15 | 6 | 9 |
| Y6 | 14 | 7 | 10 |
| Y7 | 13 | 8 | 11 |
| Y8 | 12 | 9 | 12 |
| Y9 | 11 | 10 | 14 |
| Y10 | 2 | 11 | 15 |
| X1 | 3 | 12 | 16 |
| X2 | 4 | 13 | 17 |
| X3 | 5 | 14 | 19 |
| X4 | 6 | 15 | 20 |
| X5 | 7 | 16 | 21 |
| X6 | 8 | 17 | 22 |
| X7 | 9 | 18 | 24 |
| X8 | 10 | 19 | 25 |
| X9 (DEL only) | 1 | 20 | 26 |

For this J3 prototype keep LK1, LK2 and LK3 open so X8 and X9 remain separate.
These links are for adapting other connectors to the CPC motherboard, which is
absent here. In particular LK3 shorts X8/X9. Leave bonus-switch links open for
the first bring-up. There is no matrix ground or power pin in this J3 table.

The source PCB gives J1 (membrane) and J2 (modular) different pin orders from
J3, and their routing depends on the links. Do not apply this J3 table to them.
For J1 configured as a CPC464, use the separate
[two-ribbon wiring scheme](wiring-dual-ribbon.md), [SVG](wiring-dual-ribbon.svg),
[ASCII pinout](pinout-dual-ribbon.txt) or [PDF](pinout-dual-ribbon.pdf).
That harness requires LK1 pads 1-2 and LK2 bridged, with LK3 open. J2 modular
and CPC6128 connector adaptations are not yet documented for the Pico.

## rgbwalker Cherry keyboard

Reference checkout:
`../Amstrad_CPC_464_new_Cherry_Keyboard`, revision
`588e61006bb606d08cc981467d7990c6e3104c42`.
Its README describes a 20-pin inline connector and a diode-less switch BOM.
The included `_IMAGENES_/Matriz_Teclado.jpg` is a service-manual matrix drawing,
not a netlist for every released PCB revision.

That drawing puts DEL between connector positions 1 and 2, the eight ordinary
sense lines at positions 3..10, and the nine ordinary scan lines at 11..19.
Its labels for the two DEL wires are reversed relative to Bread80's PCB net
names. With an isolated switch and no diode that reversal does not affect DEL,
but it demonstrates why these names must not be treated as a universal pinout.

For **V1.2**, the inspected fabrication archive is
`_GERBER_V1.2_/Gerber_Amstrad_Teclado_09_PCB_Amstrad_Teclado_10_THT_Con_03_2025-03-02.zip`
at the revision above. Tracing its top/bottom copper and plated holes establishes:

- CP002_THT and CP002_SMD contacts 1 through 19 connect to the same respective
  nets. Contact 20 on each footprint is isolated from the switch matrix.
- With the keys facing you, count from the **square pad at the Esc end as 1**,
  toward Shift. Count contacts 1 and 2 even though they serve only DEL.
- Esc closes contacts **5/11**, top-row `1` closes **3/11**, top-row `2` closes
  **4/11**, and DEL closes **1/2**. The first three pairs also match the firmware
  mapping derived from Bread80 J3.

Use the contact numbers in the 19-wire table for this V1.2 prototype, leaving
contact 20 disconnected. The adapter J1 shown in the SVG is drawn with contact 1
at the bottom; that is not the orientation of the keyboard header. Verify the
actual pads and cable endpoints, rather than inferring them from cable colors.
Other PCB revisions still need their own connector checks.

### Staged bring-up for rgbwalker V1.2

Unplug USB before each wiring change or meter check. Keep the keyboard isolated
from the CPC motherboard. Use direct individual jumpers for these initial tests.

1. **Start with two wires:** keyboard contact 3 to Pico physical pin 16 (GP12),
   and keyboard contact 11 to Pico physical pin 14 (GP10). With no key pressed,
   check each wire from the keyboard solder pad to its intended Pico solder pad:
   each should read close to zero ohms / beep continuously. Connect USB and press
   top-row `1`; it should type `1`. This step passed on the user's V1.2 hardware.
2. **Add `2`:** keyboard contact 4 to Pico physical pin 17 (GP13). Check the new
   wire with USB unplugged, then reconnect USB. Top-row `1` and `2` should each
   type their own digit.
3. **Add Esc:** keyboard contact 5 to Pico physical pin 19 (GP14). After checking
   its wire, verify Esc in a keyboard event viewer or an application with a known
   Esc action. Esc does not print a character.
4. **Complete the number row:** add keyboard contacts 12, 13, 14, 15 and 16 to
   Pico physical pins 12, 11, 10, 9 and 7 respectively. Check each wire, then
   power up and type `1234567890` using the top-row keys.
5. **Complete the harness:** add the remaining connections from the wire list,
   checking each pad-to-pad connection before powering up. Test every key
   individually before modifiers and chords. Keep contact 20 disconnected.

### Hardware test record: 2026-10-06

The user completed the direct harness with the existing firmware and reported
that the following tests passed:

| Test | Confirmed result |
| --- | --- |
| Initial two-wire test | Top-row `1` types `1` |
| Add contact 4 | Top-row `1` and `2` type correctly |
| Add contact 5 | Esc works; `1` and `2` still type correctly |
| Add contacts 12 through 16 | Top-row digits produce `1234567890` |
| Complete all 19 wires | `qwertyuiop`, `asdfghjkl`, `zxcvbnm` and main Enter work |

This establishes basic typing on this V1.2 prototype. Individual results for
Space, Tab, modifiers/lock keys, DEL/CLR, punctuation, cursor and keypad keys
have not yet been recorded. Chords/ghost suppression, rollover, cable timing,
USB reconnect and suspend/resume/current also need hardware checks. Other board
variants retain their separate validation status.

The original ribbon/jumper assembly produced incorrect characters and failed
the intended end-to-end wire checks. Bypassing it with the two direct wires
restored `1`; completing the direct harness then passed the tests above. This
implicates the assembly or its connections, but does not establish which
connector, contact or wire was wrong. Do not shift the entire
harness or change the keymap on that evidence alone.

To reuse a ribbon or adapter, disconnect it from the Pico and map each keyboard
pad to its actual cable endpoint with the meter. Label those endpoints before
connecting them to the Pico. Each wire must conduct without any key held.
For a **switch** continuity test, disconnect the keyboard from the Pico entirely:
the expected pair should conduct only while that key is pressed. An unpowered
Pico can provide other meter paths through its circuitry, so its attached GPIOs
are not a reliable way to identify an unknown switch pair.

## Other CPC connectors

Bread80's tactile design has the same X/Y naming but different connector
references. CPC6128 and membrane adaptations can join X8/X9 and reroute Y10.
An 18-wire adapter needs either both sense GPIOs connected to the shared X8/X9
net or a scan normalization change for DEL. Do not simply omit X9 from the
current firmware: DEL will disappear. Diode and ghosting behavior must be
checked for the exact adaptation before claiming support.

The CPC6128 SMT board is identified by upstream as unfinished. No pin-for-pin
compatibility or physical fit is assumed for it.

## Continuity and first-power checks

With the keyboard disconnected from both Pico and CPC, test these representative
switch paths:

| Key | Expected matrix path | Bread80 J3 pads |
| --- | --- | --- |
| Top-row 1 | Y9 / X1 | 11 / 3 |
| Esc | Y9 / X3 | 11 / 5 |
| Cursor Up | Y1 / X1 | 19 / 3 |
| A | Y9 / X6 | 11 / 8 |
| Space | Y6 / X8 | 14 / 10 |
| Either Shift | Y3 / X6 | 17 / 8 |
| DEL | Y10 / X9 | 2 / 1 |
| Main Enter | Y3 / X3 | 17 / 5 |
| Keypad Enter | Y1 / X7 | 19 / 9 |

Use diode mode where necessary: current flows from X through the closed switch
and diode to Y. Confirm the other contacts remain open with keys released.

After wiring, first verify USB enumeration with no keys held. Check every key
individually, then Shift/Control/Alt chords and release behavior. On diode-less
boards, try three corners of a rectangle and confirm that no fourth phantom
key is reported; some real new presses will be suppressed. On diode boards,
verify those chords with `GOODJOHN_MATRIX_HAS_DIODES=ON`. Finish by checking
unplug/replug, host suspend/resume and Num Lock behavior. The current firmware
does not provide a USB-compliant low-power suspend implementation or remote wake.

## Source provenance

- [Bread80 CPC464 PCB at the inspected revision](https://github.com/Bread80/CPC_Keyboards/blob/bf4a6052888fef27ca01a6b0983791d7cb4e8af1/Keyswitch_CPC464_SMT/Keyboard.kicad_pcb): connector nets, diode orientation and switch coordinates.
- [Bread80 documentation at the inspected revision](https://github.com/Bread80/CPC_Keyboards/blob/bf4a6052888fef27ca01a6b0983791d7cb4e8af1/README.md): shared logical matrices and board maturity.
- [rgbwalker documentation at the inspected revision](https://github.com/rgbwalker/Amstrad_CPC_464_new_Cherry_Keyboard/blob/588e61006bb606d08cc981467d7990c6e3104c42/README.md): switch type, connector family and service-manual drawing.
- [rgbwalker V1.2 fabrication archive](https://github.com/rgbwalker/Amstrad_CPC_464_new_Cherry_Keyboard/blob/588e61006bb606d08cc981467d7990c6e3104c42/_GERBER_V1.2_/Gerber_Amstrad_Teclado_09_PCB_Amstrad_Te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): THT/SMD contact correspondence, isolated contact 20 and the switch pairs recorded above.
- [Raspberry Pi Pico documentation](https://www.raspberrypi.com/documentation/microcontrollers/pico-series.html): Pico hardware and header pinout.

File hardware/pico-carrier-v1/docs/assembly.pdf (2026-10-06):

# GOODJOHN / PICO CARRIER v1

Assembly guide - 2026-10-06 - UNBUILT PROTOTYPE

USB KEYBOARD ONLY: disconnect the CPC motherboard, even when off. Use one keyboard via J1 OR J2 + J3. No CPC pass-through.


KiCad render; 80 x 66 mm board. Four 3.2 mm mounting holes.

Fit to carrier | Quantity / specification
U1 module | 1 x original RP2040 Pico / Pico H
U1 female sockets | 2 x 1-by-20; 2.54mm pitch; 17.78mm row spacing
J1 male header | 1 x 1-by-19, 2.54mm; pin 1 at BOTTOM
J2 / A and J3 / B | 2 x 1-by-10, 2.54mm; pin 1 at TOP
USB | One PC-to-Pico USB data cable supplies power

Pico USB faces the top edge. Insert U1 only after checking the unpowered carrier. Carrier headers take a mating harness, not a bare membrane tail.
Hole centres from top-left: (4,4), (76,4), (4,62), (76,62) mm.
Check actual sockets/cable fit; the carrier has not been bench-tested.

Editable project, BOM and full notes: hardware/pico-carrier-v1/README.md

# CONNECTOR CHECK SHEET

All numbers below are PHYSICAL connector contacts. GPIO is a separate column.

Net | GPIO | Pico pin | J1 inline | Ribbon carrier | Bread80 J1
X9 | GP20 | 26 | 1 | J2.9 | 17
Y10 | GP11 | 15 | 2 | J2.1 | 1
X1 | GP12 | 16 | 3 | J2.2 | 3
X2 | GP13 | 17 | 4 | J2.3 | 5
X3 | GP14 | 19 | 5 | J2.4 | 7
X4 | GP15 | 20 | 6 | J2.5 | 9
X5 | GP16 | 21 | 7 | J2.6 | 11
X6 | GP17 | 22 | 8 | J2.7 | 13
X7 | GP18 | 24 | 9 | J2.8 | 15
X8 | GP19 | 25 | 10 | J3.1 | 2
Y9 | GP10 | 14 | 11 | J3.2 | 4
Y8 | GP9 | 12 | 12 | J3.3 | 6
Y7 | GP8 | 11 | 13 | J3.4 | 8
Y6 | GP7 | 10 | 14 | J3.5 | 10
Y5 | GP6 | 9 | 15 | J3.6 | 12
Y4 | GP5 | 7 | 16 | J3.7 | 14
Y3 | GP4 | 6 | 17 | J3.8 | 16
Y2 | GP3 | 5 | 18 | J3.9 | 18
Y1 | GP2 | 4 | 19 | J3.10 | 20

J2.10 = A10 = Bread80 J1 pad 19: NO CONNECTION.
J3.10 = B10 = Bread80 J1 pad 20: Y1, required.
Bread80 ribbon mode: LK1 1-2, LK2 1-2; LK3 and bonus links OPEN.

Before USB: remove Pico, disconnect CPC, then continuity-check every cable path. Different matrix nets must be isolated; none may connect to GND or power.
Attach keyboard only after those checks. Key continuity appears only when held. Diode keyboards may need diode-test mode and the correct probe polarity.
Key | Inline carrier contacts | Pico physical pins
1 | J1.3 + J1.11 | 16 + 14
2 | J1.4 + J1.11 | 17 + 14
Esc | J1.5 + J1.11 | 19 + 14
Main Enter | J1.5 + J1.17 | 19 + 6
Space | J1.10 + J1.14 | 25 + 10
DEL / Backspace | J1.1 + J1.2 | 26 + 15

After checks, fit Pico and use the existing Goodjohn firmware with ghost suppression.
ERC / DRC / pin-map checks passed; physical fit and keyboard tests remain pending.

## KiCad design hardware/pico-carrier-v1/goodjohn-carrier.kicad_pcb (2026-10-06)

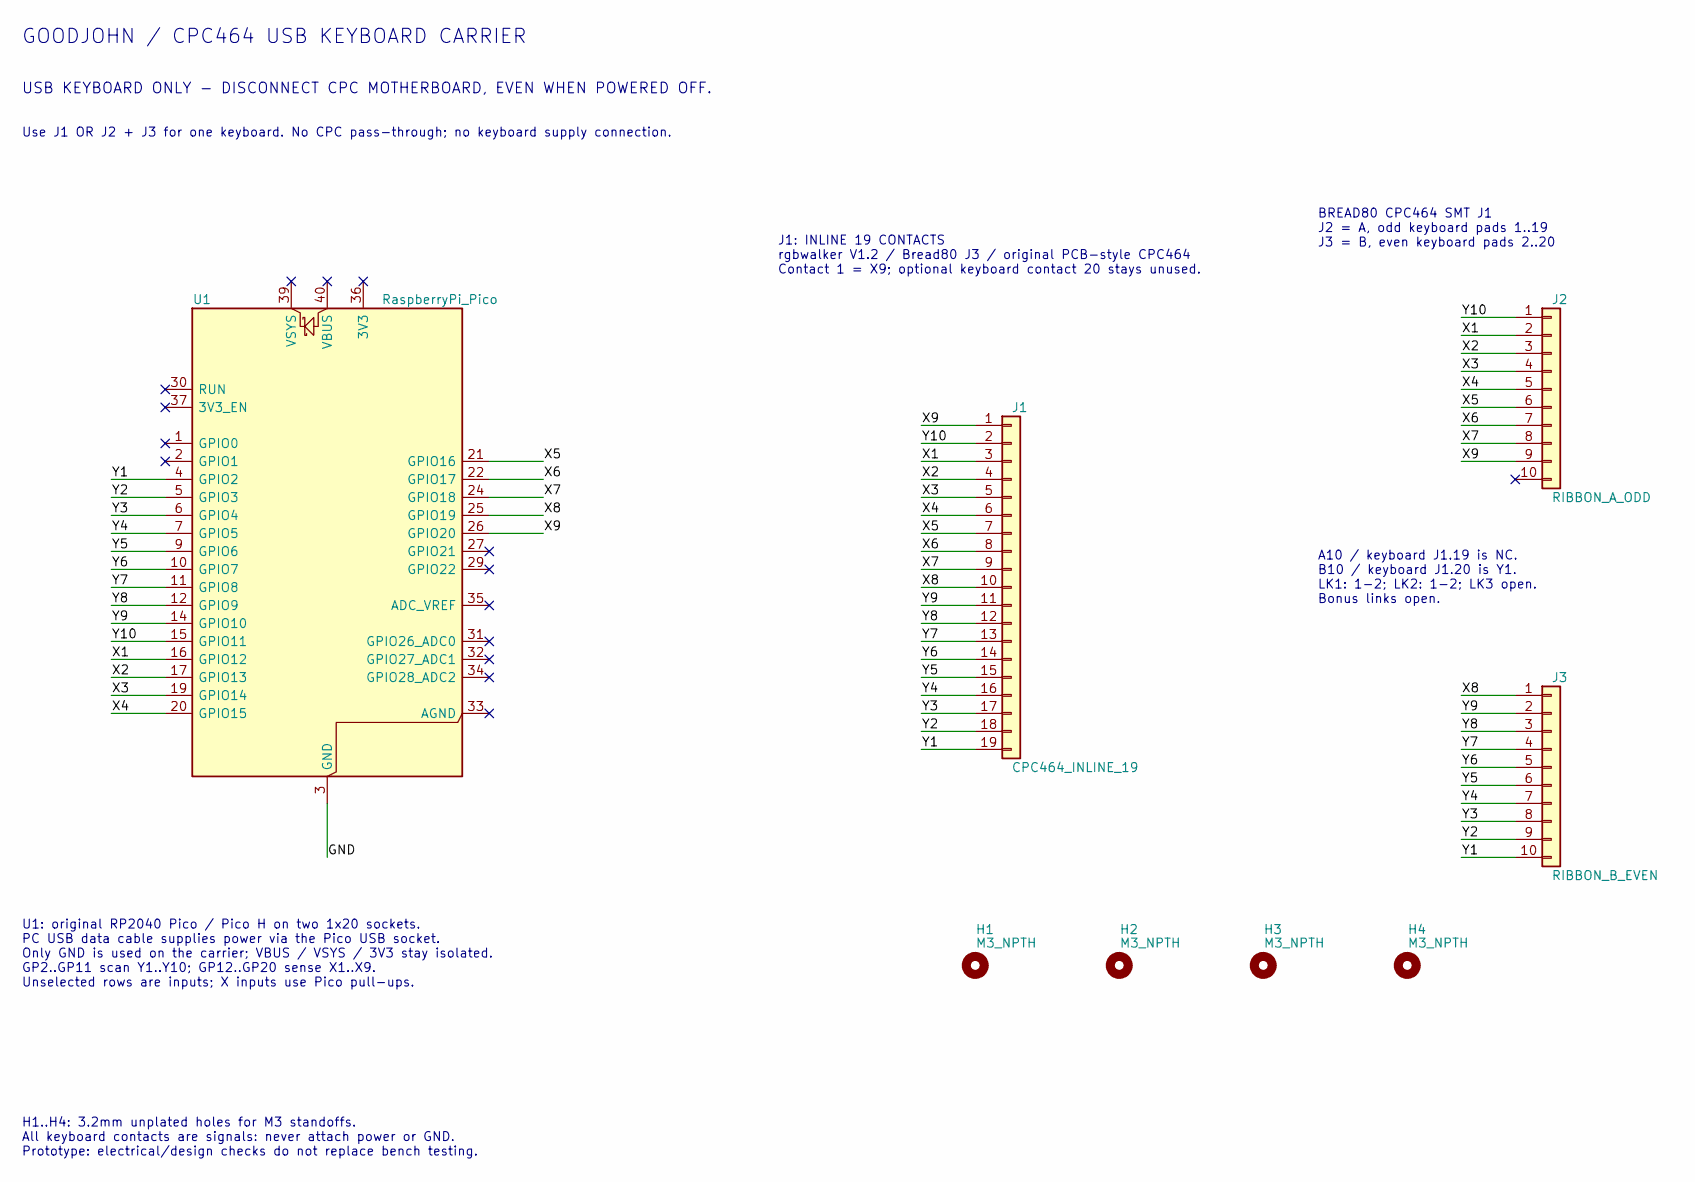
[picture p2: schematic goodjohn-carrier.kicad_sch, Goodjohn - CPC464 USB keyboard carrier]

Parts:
H1, H2, H3, H4: M3_NPTH; MountingHole_3.2mm_M3
J1: CPC464_INLINE_19; PinHeader_1x19_P2.54mm_Vertical
J2: RIBBON_A_ODD; PinHeader_1x10_P2.54mm_Vertical
J3: RIBBON_B_EVEN; PinHeader_1x10_P2.54mm_Vertical
U1: RaspberryPi_Pico; Pico_Socketed_RP2040

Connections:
/GND: U1.3 (GND), U1.8 (GND), U1.13 (GND), U1.18 (GND), U1.23 (GND), U1.28 (GND), U1.38 (GND)
/X1: J1.3, J2.2, U1.16 (GPIO12)
/X2: J1.4, J2.3, U1.17 (GPIO13)
/X3: J1.5, J2.4, U1.19 (GPIO14)
/X4: J1.6, J2.5, U1.20 (GPIO15)
/X5: J1.7, J2.6, U1.21 (GPIO16)
/X6: J1.8, J2.7, U1.22 (GPIO17)
/X7: J1.9, J2.8, U1.24 (GPIO18)
/X8: J1.10, J3.1, U1.25 (GPIO19)
/X9: J1.1, J2.9, U1.26 (GPIO20)
/Y1: J1.19, J3.10, U1.4 (GPIO2)
/Y2: J1.18, J3.9, U1.5 (GPIO3)
/Y3: J1.17, J3.8, U1.6 (GPIO4)
/Y4: J1.16, J3.7, U1.7 (GPIO5)
/Y5: J1.15, J3.6, U1.9 (GPIO6)
/Y6: J1.14, J3.5, U1.10 (GPIO7)
/Y7: J1.13, J3.4, U1.11 (GPIO8)
/Y8: J1.12, J3.3, U1.12 (GPIO9)
/Y9: J1.11, J3.2, U1.14 (GPIO10)
/Y10: J1.2, J2.1, U1.15 (GPIO11)

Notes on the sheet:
GOODJOHN / CPC464 USB KEYBOARD CARRIER
USB KEYBOARD ONLY - DISCONNECT CPC MOTHERBOARD, EVEN WHEN POWERED OFF.
Use J1 OR J2 + J3 for one keyboard. No CPC pass-through; no keyboard supply connection.
U1: original RP2040 Pico / Pico H on two 1x20 sockets. PC USB data cable supplies power via the Pico USB socket. Only GND is used on the carrier; VBUS / VSYS / 3V3 stay isolated. GP2..GP11 scan Y1..Y10; GP12..GP20 sense X1..X9. Unselected rows are inputs; X inputs use Pico pull-ups.
J1: INLINE 19 CONTACTS rgbwalker V1.2 / Bread80 J3 / original PCB-style CPC464 Contact 1 = X9; optional keyboard contact 20 stays unused.
BREAD80 CPC464 SMT J1 J2 = A, odd keyboard pads 1..19 J3 = B, even keyboard pads 2..20
A10 / keyboard J1.19 is NC. B10 / keyboard J1.20 is Y1. LK1: 1-2; LK2: 1-2; LK3 open. Bonus links open.
H1..H4: 3.2mm unplated holes for M3 standoffs. All keyboard contacts are signals: never attach power or GND. Prototype: electrical/design checks do not replace bench testing.

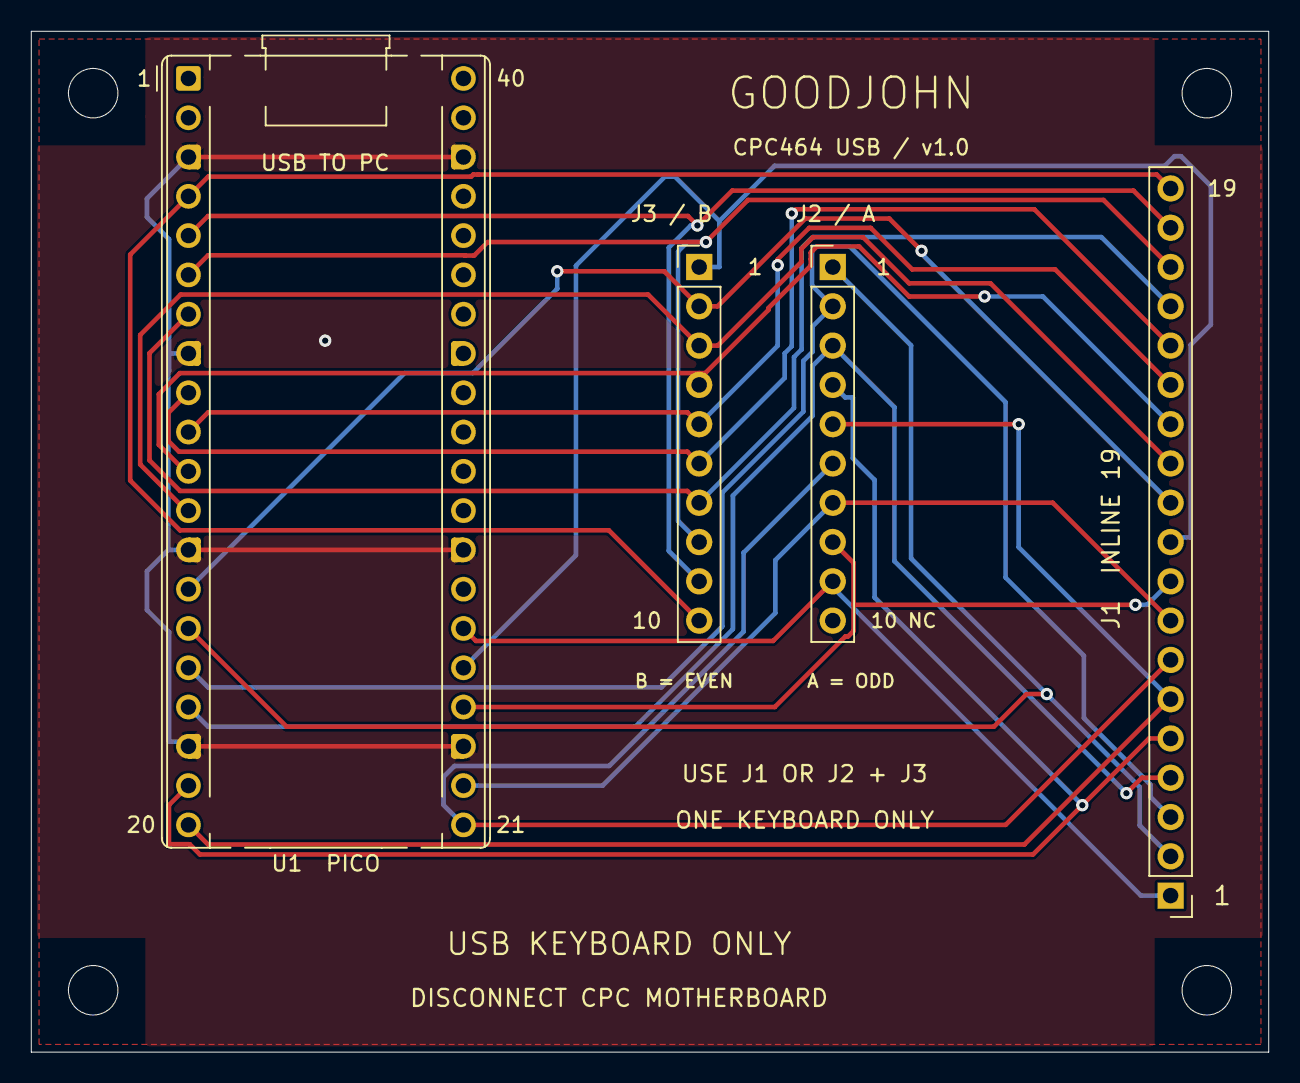
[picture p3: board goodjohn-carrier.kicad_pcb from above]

Board: 2 copper layers, 80.0 x 66.0 mm, 8 parts (0 on the bottom side), 20 nets.

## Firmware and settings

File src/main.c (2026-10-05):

#include <string.h>
#include "pico/stdlib.h"
#include "tusb.h"
#include "board_config.h"
#include "matrix.h"

static keyboard_report_t current_report;
static keyboard_report_t last_report;
static bool sent_report;
static uint8_t idle_rate; /* HID units: 4 ms, zero means changes only. */
static uint32_t last_report_ms;
static uint8_t host_leds;

void tud_mount_cb(void) {
    sent_report = false;
    idle_rate = 0;
}

void tud_umount_cb(void) {
    sent_report = false;
    host_leds = 0;
}

void tud_resume_cb(void) {
    sent_report = false;
}

bool tud_hid_set_idle_cb(uint8_t instance, uint8_t rate) {
    (void)instance;
    idle_rate = rate;
    return true;
}

uint16_t tud_hid_get_report_cb(uint8_t instance, uint8_t report_id,
                              hid_report_type_t type, uint8_t *buffer, uint16_t length) {
    if (instance != 0 || report_id != 0) return 0;
    if (type == HID_REPORT_TYPE_OUTPUT) {
        if (length == 0) return 0;
        buffer[0] = host_leds;
        return 1;
    }
    if (type != HID_REPORT_TYPE_INPUT) return 0;
    if (length > sizeof(current_report)) length = sizeof(current_report);
    memcpy(buffer, &current_report, length);
    return length;
}

void tud_hid_set_report_cb(uint8_t instance, uint8_t report_id,
                          hid_report_type_t type, const uint8_t *buffer, uint16_t length) {
    if (instance == 0 && report_id == 0 && type == HID_REPORT_TYPE_OUTPUT && length) {
        host_leds = buffer[0]; /* Reserved for lock LEDs on the interface board. */
    }
}

int main(void) {
    matrix_init();
    tusb_init();
    keyboard_t keyboard = {0};
    uint32_t last_scan_us = time_us_32();

    while (true) {
        tud_task();
        uint32_t now_us = time_us_32();
        uint32_t now_ms = to_ms_since_boot(get_absolute_time());
        if ((uint32_t)(now_us - last_scan_us) >= MATRIX_SCAN_INTERVAL_US) {
            last_scan_us = now_us;
            matrix_row_t raw[MATRIX_ROWS];
            matrix_scan(raw);
            keyboard_update(&keyboard, raw, now_ms, GOODJOHN_MATRIX_HAS_DIODES);
            keyboard_report(&keyboard, &current_report);
        }
        bool changed = !sent_report || memcmp(&last_report, &current_report, sizeof(last_report)) != 0;
        bool idle_due = idle_rate && (uint32_t)(now_ms - last_report_ms) >= (uint32_t)idle_rate * 4u;
        if (tud_hid_ready() && (changed || idle_due)) {
            if (tud_hid_keyboard_report(0, current_report.modifiers, current_report.keys)) {
                last_report = current_report;
                last_report_ms = now_ms;
                sent_report = true;
            }
        }
    }
}

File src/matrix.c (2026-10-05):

#include "matrix.h"
#include "board_config.h"
#include "pico/stdlib.h"

void matrix_init(void) {
    for (unsigned row = 0; row < MATRIX_ROWS; ++row) {
        gpio_init(row_gpios[row]);
        gpio_disable_pulls(row_gpios[row]);
        gpio_put(row_gpios[row], 0);
        gpio_set_dir(row_gpios[row], GPIO_IN);
    }
    for (unsigned col = 0; col < MATRIX_COLS; ++col) {
        gpio_init(col_gpios[col]);
        gpio_set_dir(col_gpios[col], GPIO_IN);
        gpio_pull_up(col_gpios[col]);
    }
}

void matrix_scan(matrix_row_t raw[MATRIX_ROWS]) {
    for (unsigned row = 0; row < MATRIX_ROWS; ++row) {
        /* Only the selected cathode/row sinks current. All other rows float.
         * Driving inactive rows high would contend through diode-less switches.
         */
        gpio_set_dir(row_gpios[row], GPIO_OUT);
        sleep_us(MATRIX_SETTLE_US);
        raw[row] = 0;
        for (unsigned col = 0; col < MATRIX_COLS; ++col) {
            if (!gpio_get(col_gpios[col])) raw[row] |= (matrix_row_t)(1u << col);
        }
        gpio_set_dir(row_gpios[row], GPIO_IN);
    }
}

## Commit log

2026-10-05 Add Pico CPC USB keyboard firmware foundation
2026-10-05 Add ASCII and printable PDF keyboard pinout sheets
2026-10-05 Add minimal Pico wiring SVG and embed it in README
2026-10-06 Document successful V1.2 key test and staged wiring checks
2026-10-06 Add Bread80 J1 dual-ribbon wiring guides
2026-10-06 Add KiCad Pico carrier prototype and fabrication package
    [bom.csv, carrier.dsn, connections.csv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]
